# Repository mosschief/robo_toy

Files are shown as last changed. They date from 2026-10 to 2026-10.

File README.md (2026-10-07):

# Tank: a tough Arduino robot toy

A kid-proof robot on a printed tracked base. Its upper body turns at the waist,
the arms and waist click instead of breaking, and it has a 16 x 16 LED face,
a Wi-Fi camera and a distance sensor in the chest, and a phone control page. It reuses the electronics from
the Otto DIY "fat version" (Nano + shield, servos, LED matrix, buzzer).

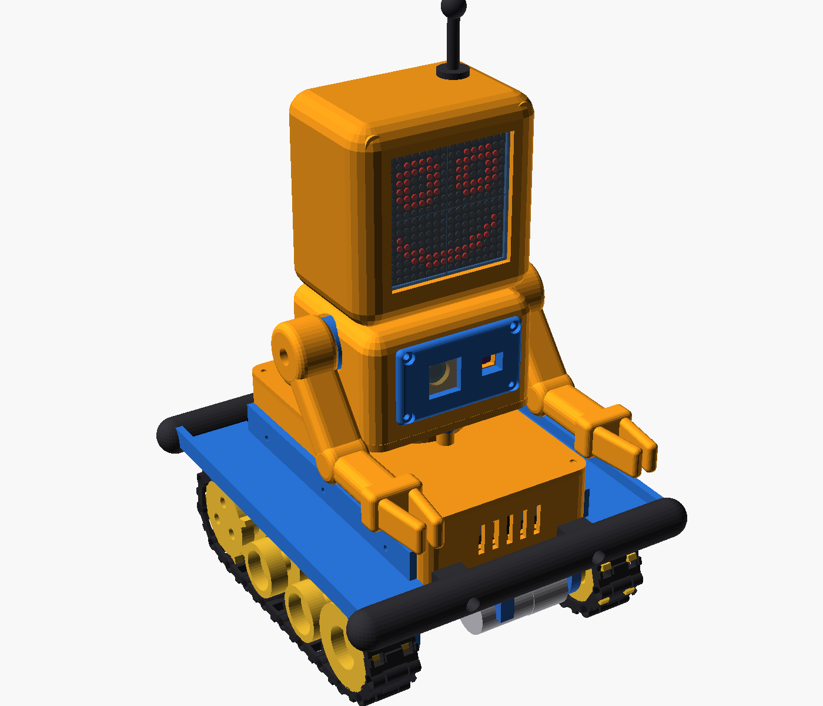
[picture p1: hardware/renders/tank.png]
Tank


| Folder | What's in it |
|---|---|
| [docs/BUILD.md](docs/BUILD.md) | parts list, printing, wiring, assembly, setup |
| [hardware/](hardware) | OpenSCAD source (`robot.scad`, `config.scad`), `stl/`, `renders/`, `export.sh` |
| [firmware/robot_body](firmware/robot_body) | Arduino Nano: face, arms, tracks, sensor, modes, `my_program.h` |
| [firmware/robot_cam](firmware/robot_cam) | ESP32-CAM: Wi-Fi, live video, phone control page |
| [tools/](tools) | `faces.txt` (draw faces) and `make_faces.py` |
| [concepts/](concepts) | the earlier concept rounds |

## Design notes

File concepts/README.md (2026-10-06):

# Robot toy concepts (round 1)

OpenSCAD concept models for a tough, kid-proof Arduino robot toy that reuses
Otto DIY Humanoid ("fat version") electronics.

- `concept_a_tank.scad`: tracks, two 2-joint arms, turning head
- `concept_b_brick.scad`: 4WD with bumper and fenders, two arms, carry handle (recommended)
- `concept_c_digger.scad`: two big wheels, turret with one 3-joint claw arm
- `tank_v2.scad`: chosen Tank, revision 2 (bought track chassis, ESP32-CAM)
- `tank_v4.scad`: current Tank (16x16 face from 4 MAX7219 modules)
- `tank_v3.scad`: Tank (camera and VL53L0X in the chest)
- `parts.scad`: shared placeholder parts (MAX7219 8x8, HC-SR04, SG90, wheels, tracks)
- `index.html` + `renders/`: concept sheet

Render a view:

```sh
xvfb-run -a openscad -o out.png --imgsize=1200,1000 \
  --camera=0,0,110,62,0,-32,820 --colorscheme=Tomorrow concepts/concept_b_brick.scad
```

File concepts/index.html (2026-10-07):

Arduino robot toy · full design

# Tank, ready to build

Everything needed to build Tank v4: 15 printable parts, a wiring plan, firmware for the Nano and the camera board, and a phone control page. All of it is in the repo on the claude/robot-toy-concepts-twiow6 branch, with step-by-step instructions in docs/BUILD.md.

## The robot

finalabout 216 × 222 × 300 mm15 printed parts

Final Tank assembly: printed orange body on a printed tracked base with link tracks, rubber bumpers, slim arms with claws, chest camera and distance sensor behind a blue guard, and a 16 by 16 LED fa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 Exploded view showing the lower body tub with battery and electronics tray, the lid, the bearing, waist plate and waist servo, the torso with its shoulder hubs, the one-piece arms and the head with 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 Printed tracked base on its own: blue deck and side frames, black printed link tracks, yellow sprockets, idlers and small road wheels, and a gear motor under the deck Rear view showing the power switch, charge port, PROG/RUN switch and Nano USB opening above the rear bumper

### How it is built

Base

Printed, a scaled-up SMARS-style design: one-piece deck and side frames, two JGA25-370 gear motors, sprockets and wheels on 608 bearings, and 21 printed links per track joined with M3 screws.

Lower body

Tub on the base deck holding the battery, Nano, motor driver, 5 V converter and charger. A lid on top carries the mode button and the waist bearing, and the waist servo stands below it.

Waist

The whole upper body turns 65° each way on a 6808 ball bearing in the lid. A clamp ring under the bearing means the robot can be picked up by its head.

Torso

Shoulder servos sit on internal bulkheads and the head bolts straight onto the top, so head, chest camera and arms turn together at the waist. The camera and distance sensor slide into rails behind the chest guard.

Head

Four 8×8 modules sit face-first in a carrier behind a 2 mm clear window. The back cap unscrews.

Arms

The slim v4 shape: one printed piece per arm with a fixed elbow bend and a two-finger claw. Only the shoulder moves.

Back panel

Power switch, USB-C charging, PROG/RUN switch and Nano USB, all above the bumper.

### Why it survives a kid

- Both shoulders and the waist have a spring clutch: a hard yank or twist makes the part click round instead of stripping the servo gears.
- Servos let go after 1.5 s of standing still, so pushing an arm by hand never fights the motor.
- PETG body with 4 walls, TPU bumpers and antenna, and the screens sit behind clear windows.
- Driving stops by itself 12 cm from a wall, and 0.4 s after the phone stops sending.
- It charges through USB-C, so the batteries never come out.

## Playing with it

Phone control page: camera view, distance and battery readout, a round orange joystick, Slow, Light and Bumper toggles, then buttons for faces, sounds, arm poses, modes and a Turn body slider

Join the Wi-Fi network Tank-XXXX (password tankrobot) and open 192.168.4.1. The page shows the camera with a joystick and buttons for faces, sounds, arm poses and modes, plus a slider that turns the body. It also shows the distance and battery readings.

Without a phone, the mode button on the lid switches modes, and the face shows the number:

Mode | What Tank does
1 Play | turns its body to look around, blinks, waves at a hand near its chest
2 Explore | drives on its own and turns away from obstacles
3 Dance | dances to a tune
4 My code | runs the program your kid writes in my_program.h
5 Face test | a wiring check for the face

Faces are drawn as text pictures in tools/faces.txt, so a kid can design new ones.

## What to buy

You already have the Otto Nano board, 3 servos, the buzzer and the LED modules (you need 4). An MG90S metal-gear servo for the waist is recommended.

Part | Qty | Approx. cost
JGA25-370 gear motors, 6 V, 130–200 rpm | 2 | $16–24
608 bearings, M8 x 45 bolts, M3 x 25 screws + nylocs for the tracks | 12 / 6 / 42 | $15
ESP32-CAM (AI-Thinker) + ESP32-CAM-MB USB adapter | 1 | $8–12
VL53L0X distance sensor (GY-VL53L0XV2) | 1 | $3
TB6612FNG motor driver | 1 | $3
6808-2RS ball bearing, 40 × 52 × 7 mm (waist) | 1 | $3–5
2 × 18650 cells, holder, 2S protection board | 1 | $12
USB-C 2S (8.4 V) charging module | 1 | $3
5 V 5 A buck converter (XL4015) | 1 | $4
Rocker switch, mini slide switch, 16 mm panel button | 1 each | $4
Compression springs ~8 mm OD × 12 mm | 3 | $3
M3 heat-set inserts, M3 and M2 screws, 5 M3 nuts | ~45 inserts | $8
2 mm clear PETG or polycarbonate sheet | small | $5
PETG and TPU filament | – | –

## Before you print

### Check the motors

JGA25-370 sellers differ in face screw spacing and shaft offset. Set MOT_* in hardware/config.scad and re-run export.sh. Print a few track links and one sprocket first and check they mesh. To use a bought TP101 chassis instead, set BASE = "bought".

### Check the LED modules

The face carrier fits the 32 × 32 mm modules (FC-16 style). If yours are the longer 50 × 32 mm boards, the carrier needs redrawing.

### Print a clutch first

Print one clutch_hub and one arm and test the click. If the click is too stiff or too loose, change the spring or CL_RH in config.scad.

### Not tested on hardware yet

Both firmwares compile, and the parts were fit-checked in the 3D model, but nothing has been printed or powered on. Expect a little tuning: servo trims, the face module order and track direction are all in config.h.

## Round 4: Tank v4

## Tank v4

chosenbought track chassisESP32-CAMVL53L0X2 arms × 2 joints

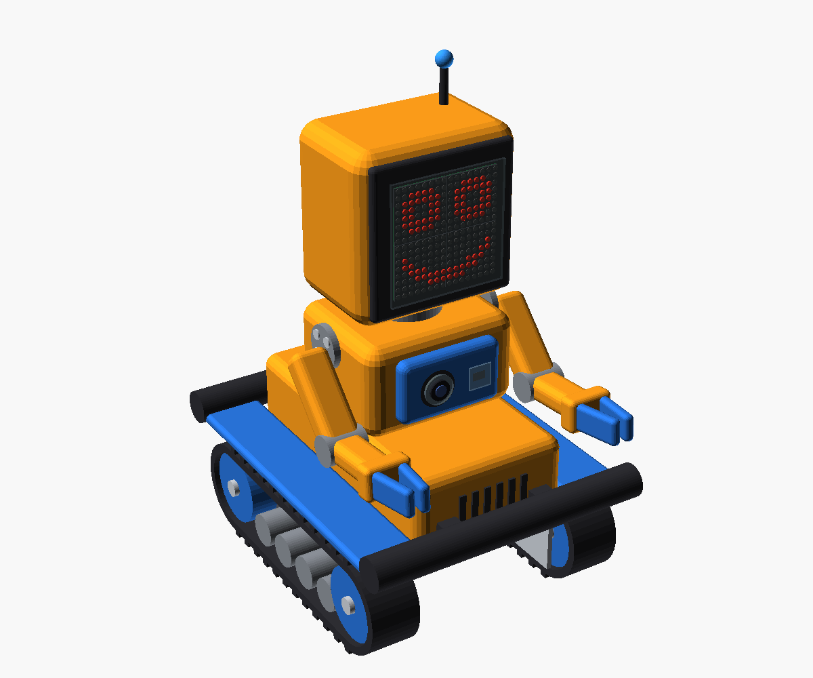
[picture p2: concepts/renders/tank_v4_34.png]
Tank v4: orange robot on a bought tank chassis with black tracks, rubber bumpers front and back, a head whose whole face is one square 16 by 16 LED display showing eyes and a smile, a camera and dis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
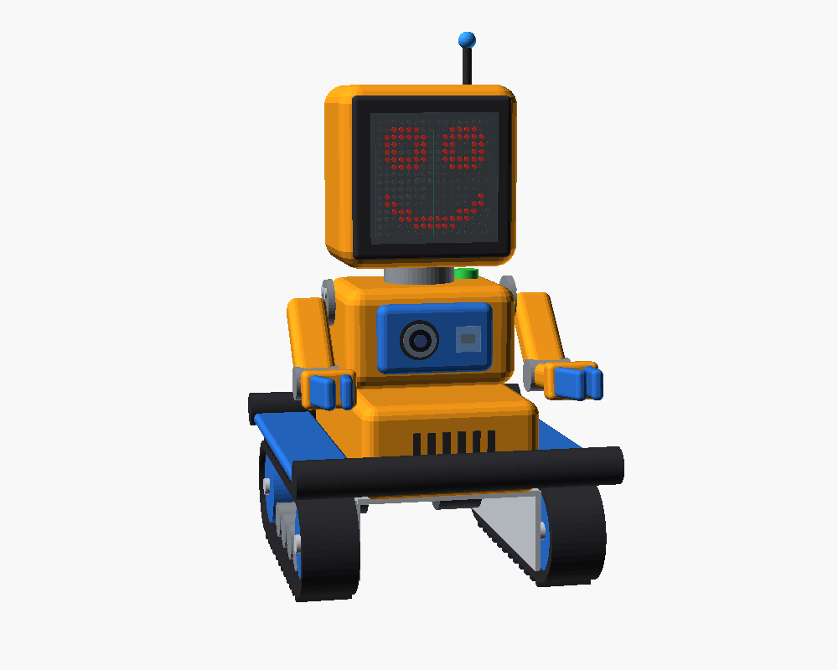
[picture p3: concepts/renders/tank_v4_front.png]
Tank v4 from the front, showing the square LED face and the camera and distance sensor in the chest
 

Size

about 172 × 222 × 270 mm tall (300 with antenna)

Drive

bought mini aluminium tank chassis, about 193 × 163 × 60 mm, metal-gear motors, plastic link tracks

Camera

ESP32-CAM (OV2640) in the chest behind a clear cover, looking where the robot drives

Distance

VL53L0X laser distance sensor beside the lens, up to about 1.2 m

Servos

5: shoulder + elbow per arm, head pan

Face

one 16×16 display (64 × 64 mm) made from four 8×8 MAX7219 modules in a square, on one chain; eyes and mouth are drawn on it, so they can move, blink, wink or turn into hearts

Chest

camera and distance sensor under a raised guard; buzzer grille on the lower body; power button on the shoulder

### What the camera adds

- Live video to a phone or tablet over Wi-Fi, with on-screen driving buttons, so your kid sees what the robot sees
- Simple vision tricks on the ESP32: follow a coloured ball, react when a face appears
- The distance sensor brings back "stop before the wall" and lets it measure how far away the ball is

### Trade-offs

- The camera no longer turns with the head, so to look around the robot turns its whole body
- The chest guard takes the hits the head used to avoid, so the lens sits behind a 2 mm clear cover recessed 3 mm

## How the electronics split

### ESP32-CAM: eyes and Wi-Fi

Runs the camera, the phone web page and any vision code. It sends short commands like "drive forward" or "happy face" to the Nano over a serial link (two wires, plus a two-resistor divider because the ESP32 is 3.3 V).

### Otto Nano: body

Keeps doing what it does in Otto: servos, the 16×16 face, the buzzer, and now the motor driver. It also reads the VL53L0X over I2C (pins A4 and A5), so it can stop by itself even with Wi-Fi off. Programmed in the Arduino IDE exactly as before, so it still works on its own without the camera.

### Bought chassis

The tracks, sprockets, road wheels and motors come as one tested unit. The printed body bolts to its aluminium deck with four M3 screws, and printed fenders cover the tracks so fingers stay out.

### Power

2 × 18650 cells (7.4 V) in the chassis feed the motors through the driver, and a 5 V 3 A buck converter feeds the Nano, servos, matrices and camera.

## Tank v4 parts list

Prices are typical Amazon/AliExpress prices in October 2026 and vary by seller.

Part | Qty | Source | Approx. cost
Otto Nano board + I/O shield | 1 | Have | –
Micro servos (MG90S metal gear recommended for the arms) | 5 | Have SG90s | $10 for 4 MG90S
MAX7219 8×8 matrix | 4 | Have (Otto + Amazon pack); buy one more if you only have 3 | –
Buzzer, Dupont cables | ✓ | Have | –
Mini aluminium tank chassis with motors ("mini TP101" style) | 1 | New | $35–65
ESP32-CAM (AI-Thinker, OV2640) + ESP32-CAM-MB USB adapter | 1 | New | $8–12
Motor driver (TB6612FNG or DRV8833) | 1 | New | $3
2 × 18650 holder with protection board + cells | 1 | New | $12
5 V 3 A buck converter + rocker switch | 1 | New | $4
VL53L0X distance sensor | 1 | New | $3
PETG + TPU filament | – | New | –

## Round 1 concepts

## A · Tank

tracks2 arms × 2 jointsturning head

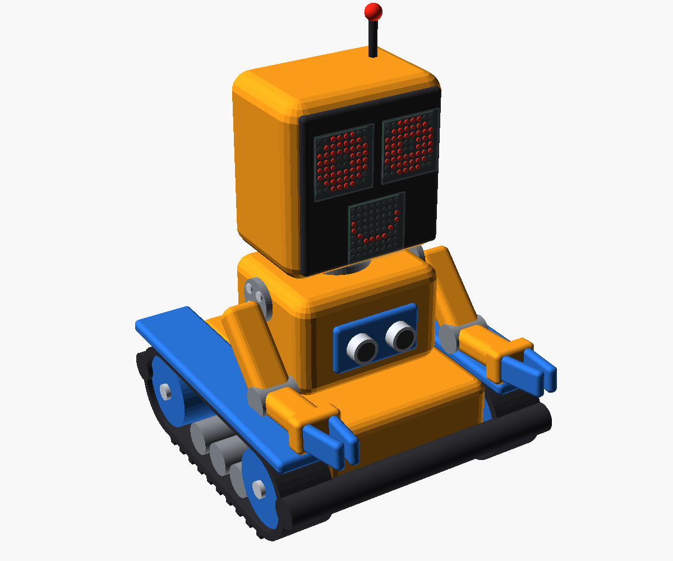
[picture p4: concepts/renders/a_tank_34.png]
Tank concept: orange robot on blue and black tracks with a square head showing two LED-matrix eyes and a smiling matrix mouth, ultrasonic sensor in the chest, two arms with claws
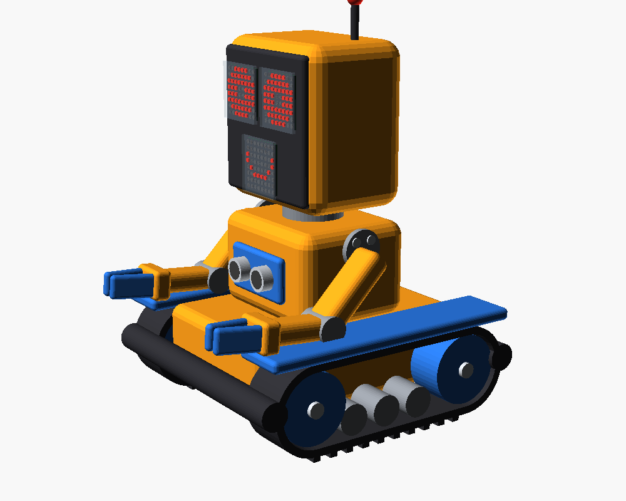
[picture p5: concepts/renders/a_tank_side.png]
Tank concept from the right side
 

A classic tracked robot with a square head that turns left and right. Both arms have a shoulder and an elbow and end in fixed claws, so it can push, scoop and wave.

Size

about 180 × 185 × 265 mm tall (with antenna)

Drive

2 gear motors, TPU tracks with grousers

Servos

5: shoulder + elbow per arm, head pan

Eyes

two more 8×8 matrices chained to the mouth

Sensor

HC-SR04 in the chest behind a guard

- Climbs over toys and rugs
- Most "robot" looking, the head turn is very expressive
- Printed tracks are the most failure-prone part of all three designs
- Tall, so it is the one most likely to tip on a hard turn
- Longest print and assembly

## B · Brick

recommended4WD2 arms with gripperscarry handle

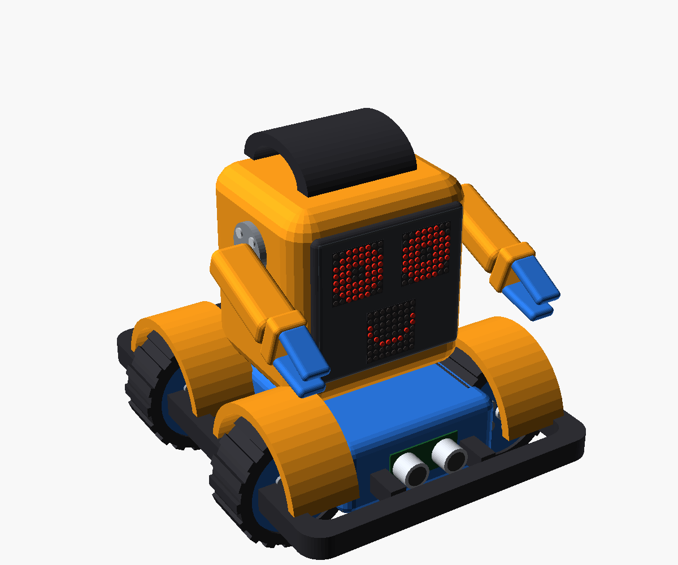
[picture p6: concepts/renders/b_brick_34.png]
Brick concept: rounded orange block body on a blue chassis with four chunky black tyres under orange fenders, a black rubber bumper all around, LED-matrix face behind a window, two arms with blue gr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
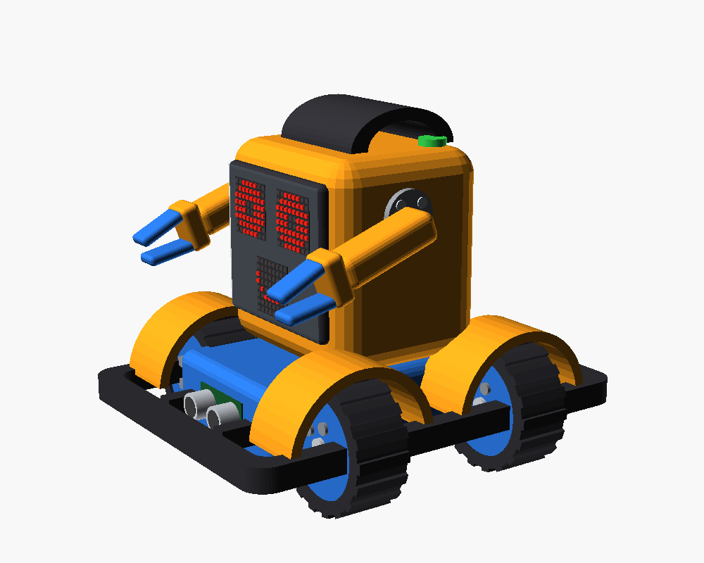
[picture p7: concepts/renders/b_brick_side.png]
Brick concept from the right side
 

One big rounded block for head and body, low and wide on four skid-steer wheels. The whole face (two eye matrices and the mouth) sits behind one clear window, and the handle on top lets your kid carry it around.

Size

about 190 × 250 × 205 mm tall

Drive

4 gear motors (or 2 driven + 2 idlers), TPU tyres

Servos

2 to 4: shoulder per arm, optional gripper per arm

Eyes

two more 8×8 matrices chained to the mouth

Sensor

HC-SR04 in the front grille, behind the bumper

- Toughest: bumper and fenders take every hit before the body does
- Low centre of gravity, very hard to flip
- Simplest to print and to repair
- No head turn (could add one later as a neck servo)
- Arms are simpler than the Tank's

## C · Digger

2 big wheels1 claw arm × 3 jointsrotating turret

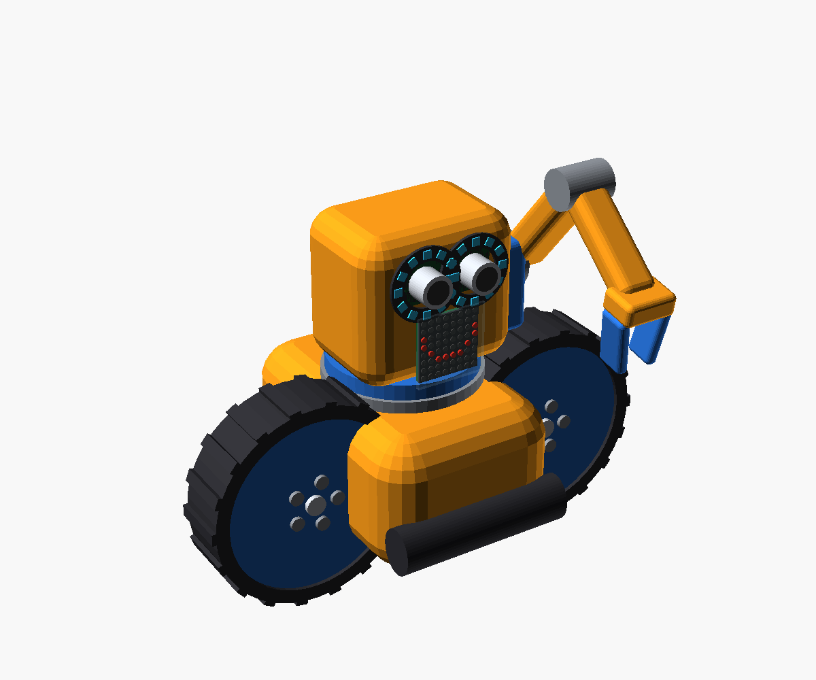
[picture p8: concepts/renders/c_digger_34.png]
Digger concept: two large black wheels on a rounded orange pod, a rotating turret head with ultrasonic sensor eyes ringed by blue LED rings, an LED-matrix mouth, and one long jointed arm with a claw
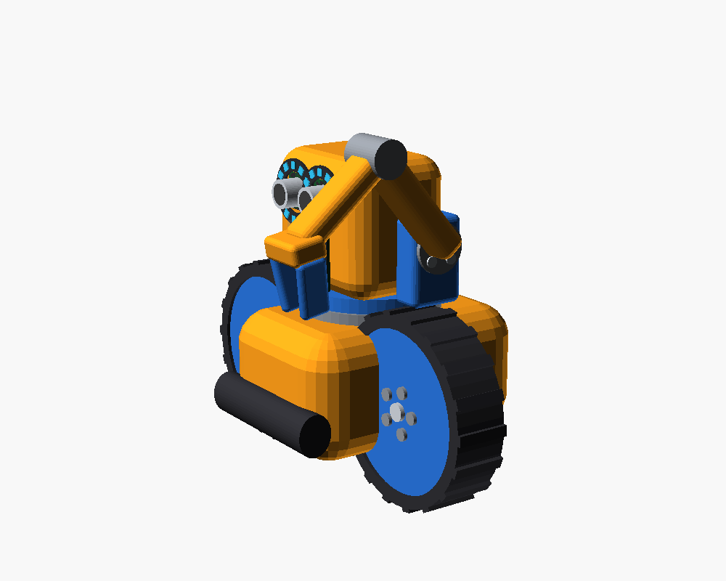
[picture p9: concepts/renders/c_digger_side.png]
Digger concept from the right side
 

Two big wheels taller than the body plus a rear skid, with a turret on top carrying one long excavator-style arm. The ultrasonic sensor becomes the eyes, like Otto, ringed with colour LED rings.

Size

about 165 × 160 × 230 mm tall (arm raised)

Drive

2 gear motors, 104 mm TPU tyres, rear skid

Servos

4: turret, shoulder, elbow, claw

Eyes

2 × WS2812 12-LED rings around the HC-SR04

Sensor

HC-SR04 as the eyes

- The arm can actually pick things up
- Big wheels roll over obstacles and protect the body
- Familiar Otto face
- One long arm is a lever: it is the part most likely to get yanked
- Needs new LED rings for the eyes
- Turns in place but the skid drags on carpet

## Parts: what you have vs. what's new

Otto "fat version" kit parts are from its Printables bill of materials. I couldn't open the Amazon listing, so I've assumed it is the common MAX7219 8×8 module (32 × 32 mm, 5-pin); tell me if it's different.

Part | A · Tank | B · Brick | C · Digger | Source
Otto Nano board + I/O shield | 1 | 1 | 1 | Otto kit
Micro servos (SG90 or MG90S) | 5 | 2–4 | 4 | Otto kit (has 6)
HC-SR04 ultrasonic | 1 | 1 | 1 | Otto kit
MAX7219 8×8 matrix (mouth) | 1 | 1 | 1 | Otto kit / your Amazon pack
MAX7219 8×8 matrix (eyes) | 2 | 2 | – | Your Amazon pack, if it's a multi-pack
Buzzer, Dupont cables | ✓ | ✓ | ✓ | Otto kit
Gear motors (metal-gear N20 or TT) | 2 | 2–4 | 2 | New
Motor driver (DRV8833 or TB6612) | 1 | 1–2 | 1 | New
WS2812 12-LED rings | – | – | 2 | New
2 × 18650 holder + 5 V 3 A buck + switch | 1 | 1 | 1 | New (the Otto battery can't run drive motors and servos together)
TPU filament (tyres, tracks, bumpers) | most | some | some | New

Pin budget fits the Nano in every concept: all three matrices share one 3-wire chain, the motor driver takes 4 PWM pins (3, 5, 6, 11), the HC-SR04 2 pins, the buzzer 1, and servos go on the remaining pins. Otto's Bluetooth module would still fit for phone control.

## How it stays in one piece

### Arms that give way

Each arm attaches to its servo through a magnetic or spring-detent coupler, so a yank pops the arm off instead of stripping the servo gears. Arms get metal-gear MG90S servos, which are drop-in replacements for the SG90.

### Soft outside, hard inside

Tyres, tracks, bumpers and the handle are TPU. The shell is PETG with 4 walls and 30% gyroid infill, not PLA, which goes brittle and cracks on drops.

### Protected screens

The matrices sit recessed behind a 2 mm polycarbonate or PETG window, so little fingers and crashes never touch the LEDs.

### Floating electronics

The Nano, driver and buck converter sit on one tray on foam pads, with heat-set brass inserts instead of screws threaded into plastic, so it can be opened and fixed many times.

### Kid-safe power

Lithium cells live behind a screwed battery door with a protected charger. Any magnets are fully enclosed inside printed parts; for a child under about 6 I'd use the spring detent instead of magnets.

### Programmable

Standard Arduino IDE (and Otto Blockly-style blocks later), with a small library of moves, faces and sounds so new tricks are a few lines of code.

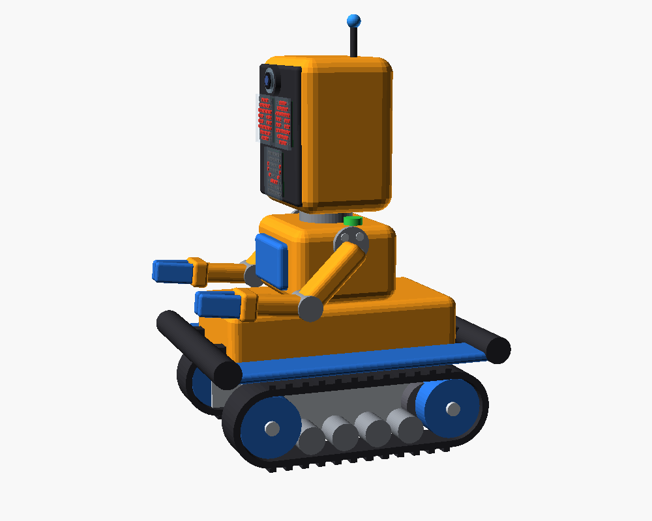
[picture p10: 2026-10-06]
concepts/renders/tank_v2_side.png

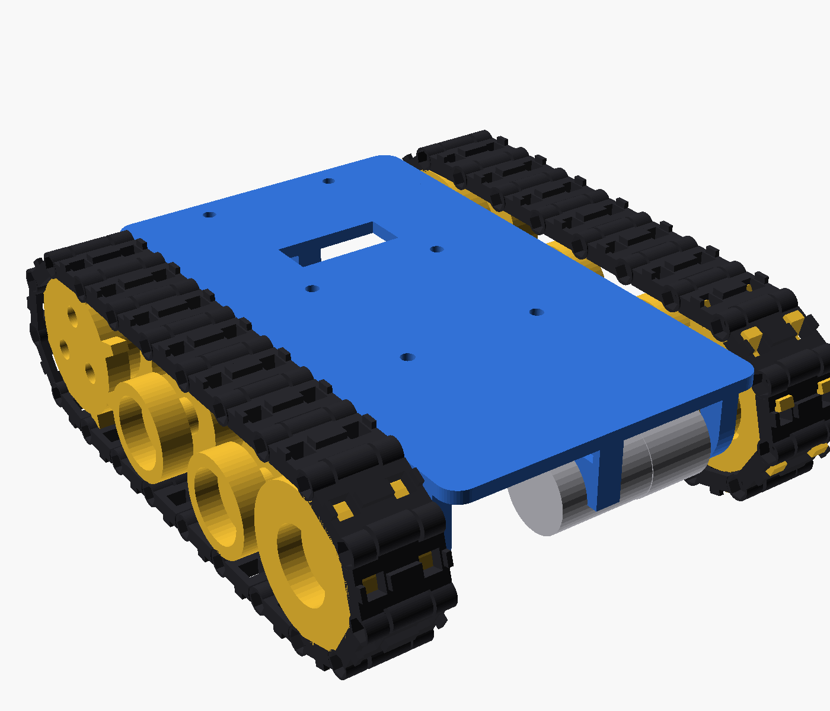
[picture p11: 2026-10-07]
hardware/renders/base.png

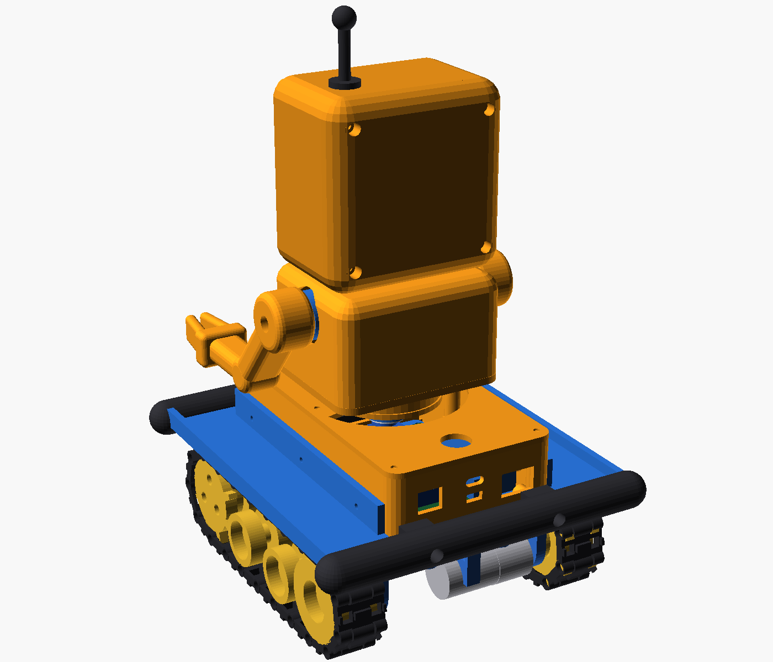
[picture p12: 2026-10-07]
hardware/renders/tank_back.png

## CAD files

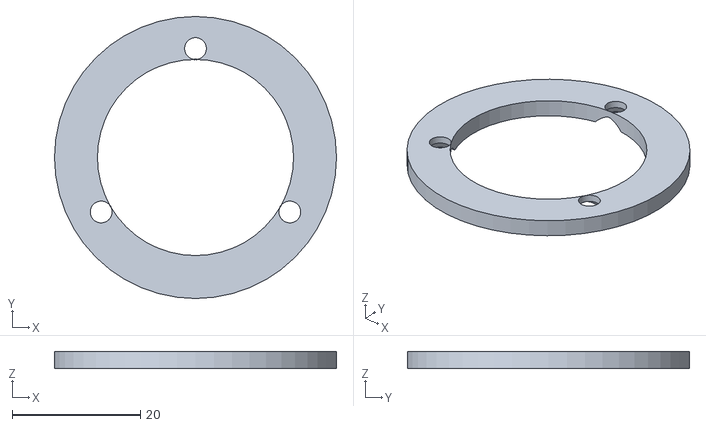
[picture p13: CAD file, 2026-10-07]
hardware/stl/clamp_ring.stl
44.0 x 44.0 x 2.70

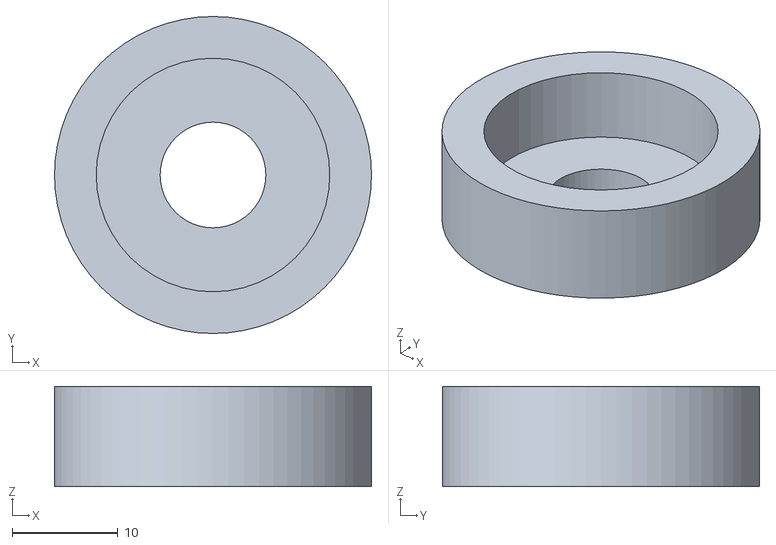
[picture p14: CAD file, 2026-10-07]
hardware/stl/road_wheel_half.stl
30.0 x 30.0 x 9.50

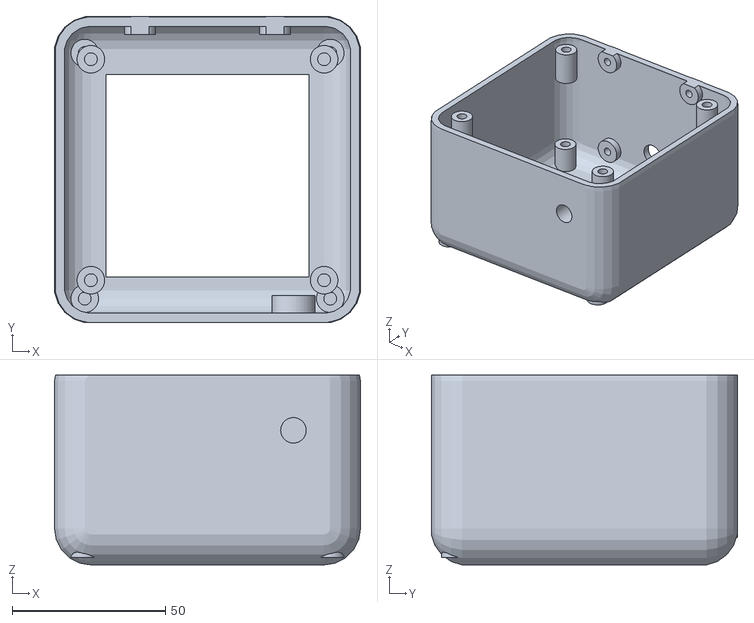
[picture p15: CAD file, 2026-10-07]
hardware/stl/head_front.stl
99.7 x 99.9 x 61.9

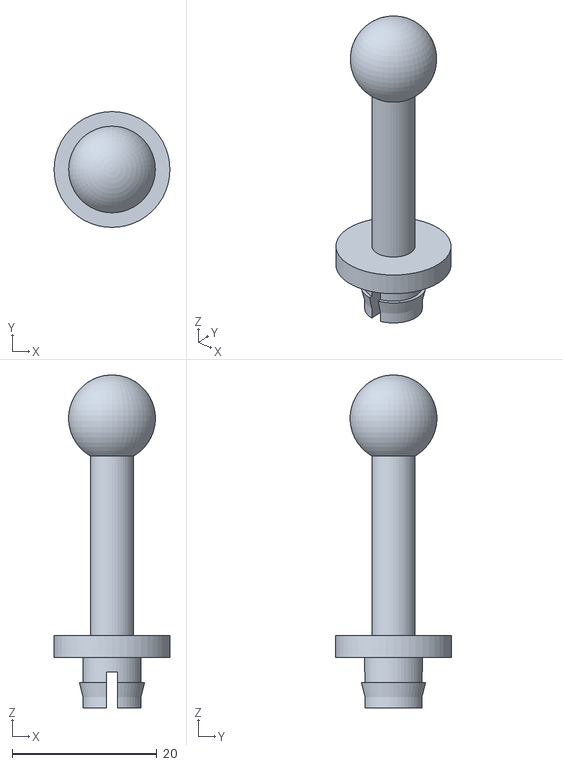
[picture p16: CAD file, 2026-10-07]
hardware/stl/antenna.stl
16.0 x 16.0 x 46.0

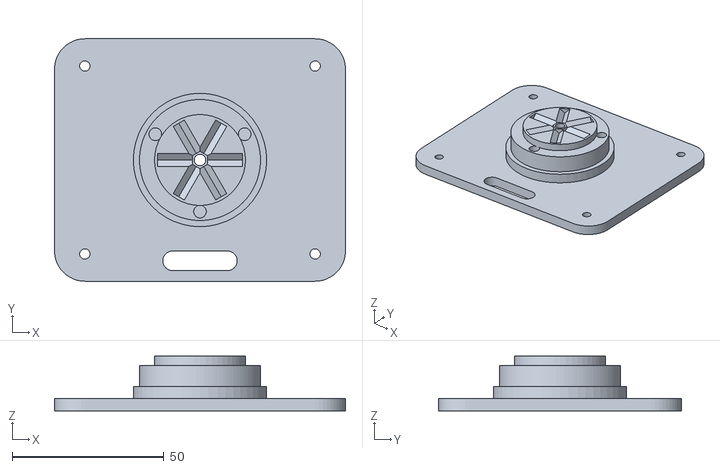
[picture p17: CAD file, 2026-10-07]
hardware/stl/waist.stl
96.0 x 80.0 x 18.0

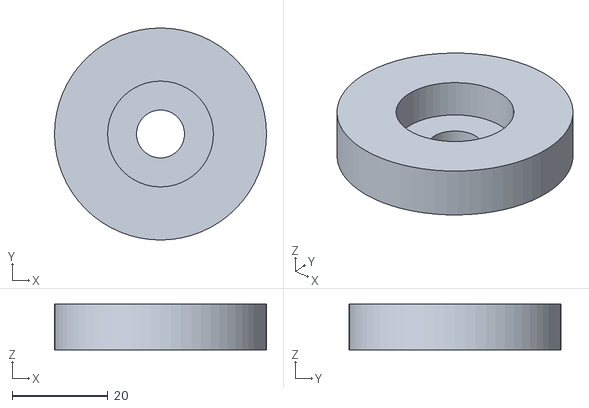
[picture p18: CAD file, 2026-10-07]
hardware/stl/wheel_half.stl
44.3 x 44.3 x 9.50

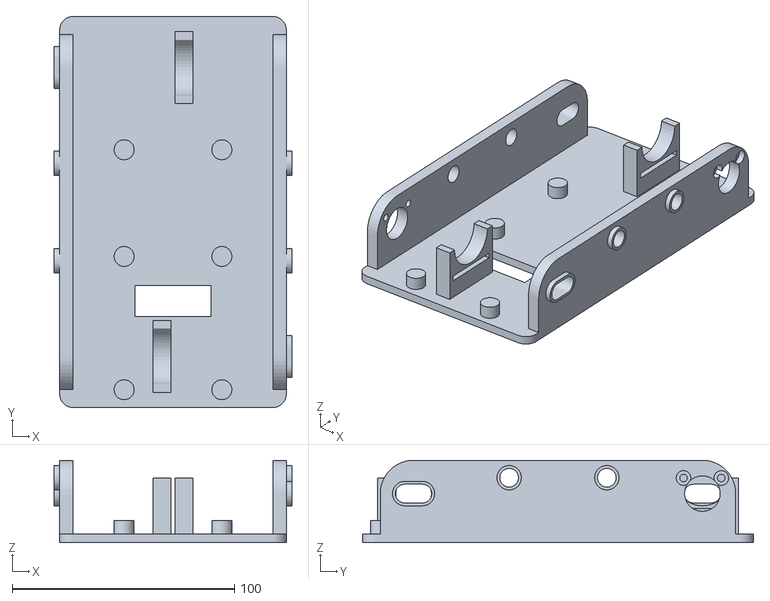
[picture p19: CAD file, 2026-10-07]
hardware/stl/base_frame.stl
107.0 x 176.0 x 37.1

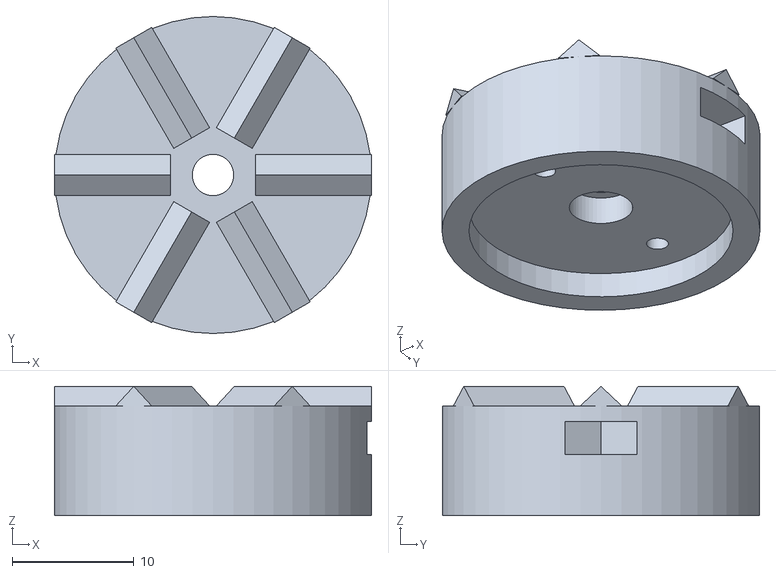
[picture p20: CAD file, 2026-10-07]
hardware/stl/clutch_hub.stl
26.0 x 26.0 x 10.6

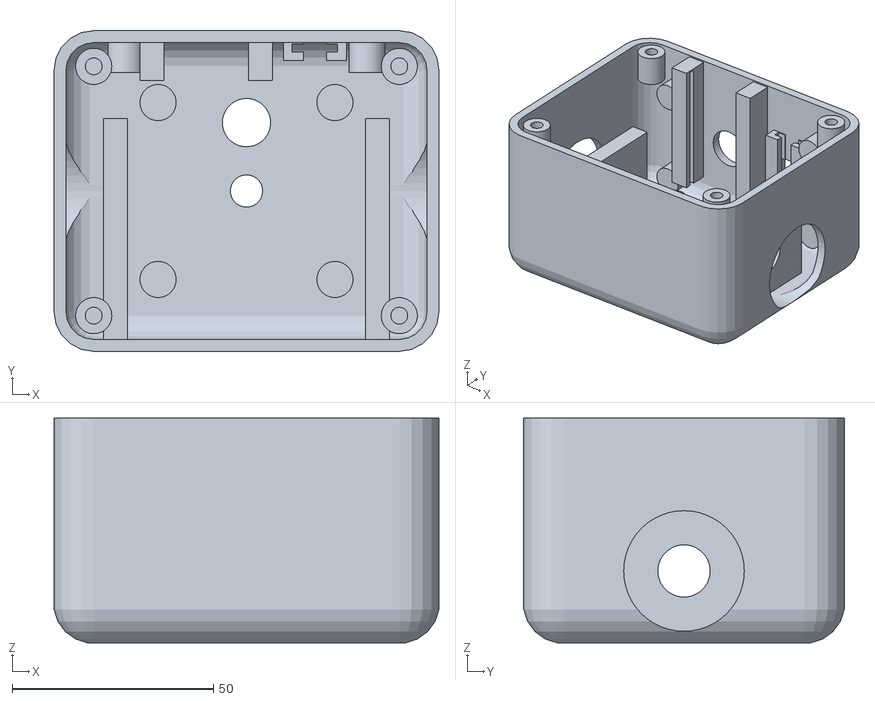
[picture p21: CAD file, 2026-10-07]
hardware/stl/torso.stl
95.8 x 79.8 x 55.9

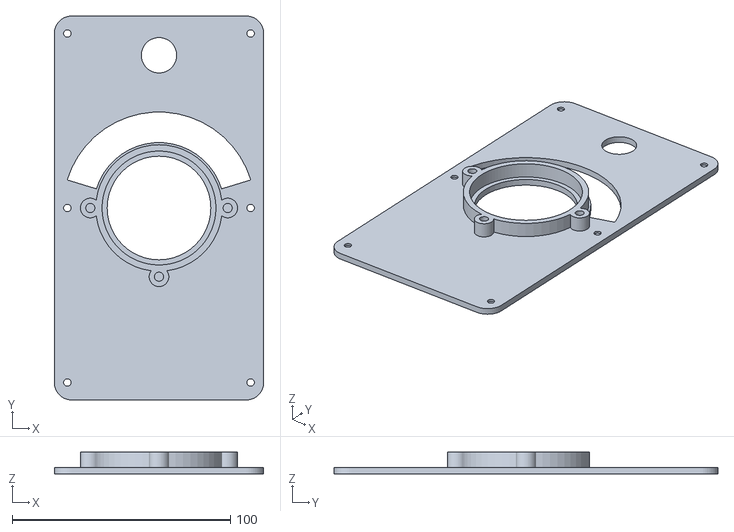
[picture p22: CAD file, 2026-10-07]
hardware/stl/lid.stl
96.0 x 176.0 x 10.0

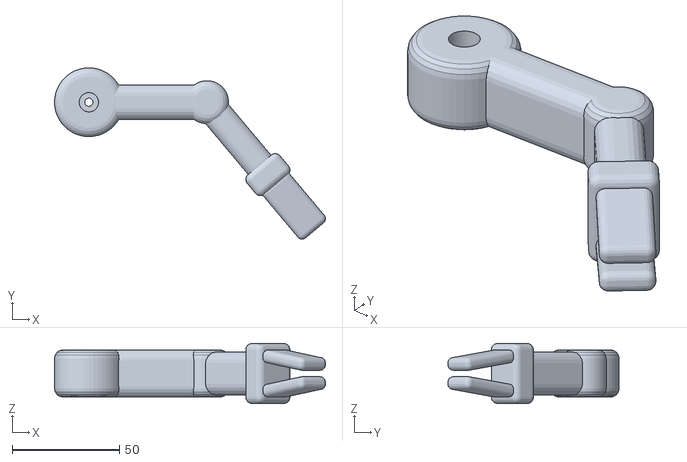
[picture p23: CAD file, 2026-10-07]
hardware/stl/arm.stl
126.1 x 79.7 x 27.9

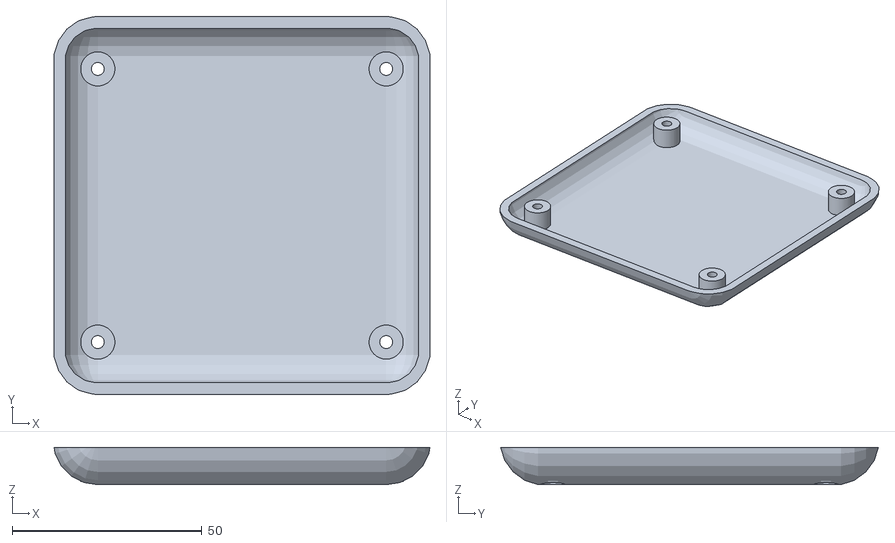
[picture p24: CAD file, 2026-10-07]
hardware/stl/head_back.stl
99.1 x 99.6 x 9.85

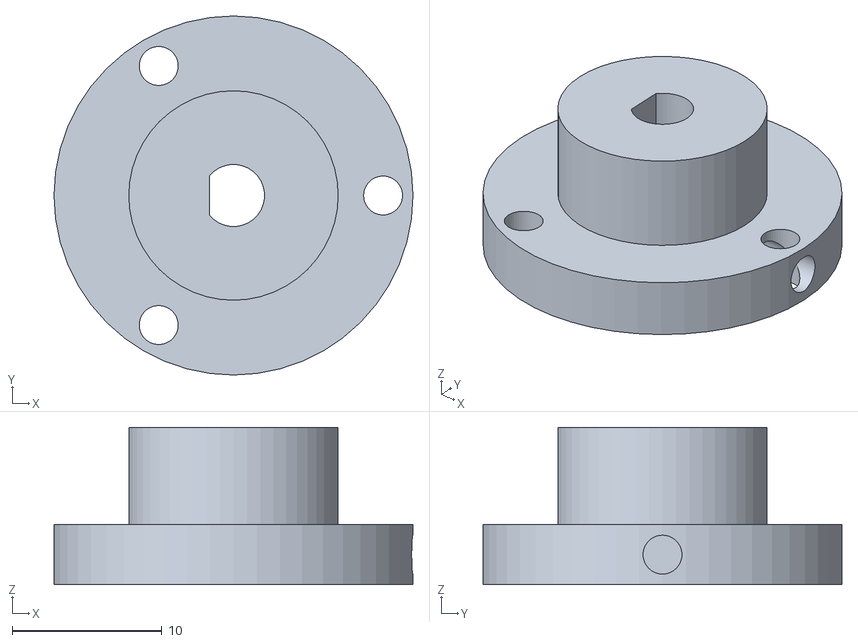
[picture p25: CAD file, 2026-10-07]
hardware/stl/sprocket_hub.stl
24.0 x 24.0 x 10.5

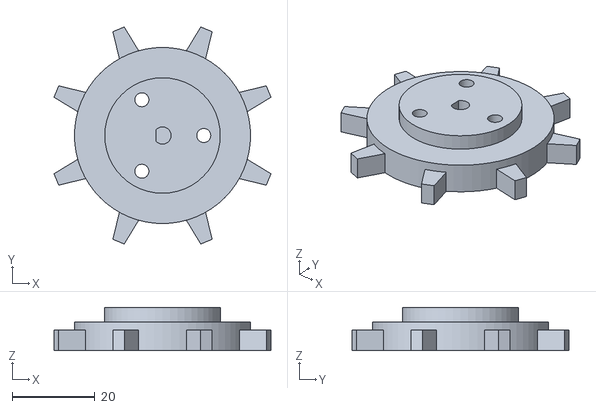
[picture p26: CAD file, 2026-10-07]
hardware/stl/sprocket_half.stl
52.6 x 52.6 x 10.5

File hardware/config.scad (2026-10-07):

// Tank robot: every dimension in one place (mm).
// Change these to match the parts you actually bought, then re-export.

$fn = 48;

// ---------- print / fasteners ----------
WALL      = 3;      // shell wall. Print PETG, 4 perimeters, 30% gyroid.
INS_D     = 4.2;    // hole for an M3 x 5.7 brass heat-set insert
INS_L     = 6;
BOSS_D    = 9;
M3        = 3.4;    // M3 clearance
M3_HEAD   = 6.6;    // M3 socket head counterbore
M2_PILOT  = 1.8;    // servo tab screws (self-tapping M2)
NUT_AF    = 5.9;    // M3 nut across flats (+clearance)
NUT_T     = 2.7;
CLR       = 0.3;    // general fit clearance

// ---------- MG90S / SG90 micro servo ----------
SV_L      = 22.8;   // body length (long axis)
SV_W      = 12.2;   // body width
SV_TAB_L  = 32.2;   // length across mounting tabs
SV_TAB_T  = 2.5;    // tab thickness
SV_BELOW  = 15.9;   // body bottom to underside of tabs
SV_ABOVE  = 4.3;    // top of tabs to top of body
SV_SPLINE = 12.6;   // top of tabs to tip of output spline
SV_SCREW  = 27.8;   // tab screw hole spacing
SV_SHAFT  = 5.6;    // output shaft offset from body centre along long axis
SV_DOME_D = 12.0;   // gear dome around the spline

// Round "disk" servo horn that comes with the servo
HORN_D    = 21.0;
HORN_T    = 2.0;
HORN_HOLE_R = 7.5;  // radius of the screw holes used to fix horn to the clutch hub

// ---------- breakaway clutch (one design, used at the shoulders and the waist) ----------
// Horn hub (on the servo) has radial V ridges; the limb has matching grooves.
// An M3 screw + compression spring (8 mm OD, ~12 mm long) presses them together.
// A hard yank makes the limb click round instead of stripping servo gears.
CL_D      = 26;
CL_T      = 9;      // hub body thickness
CL_RIDGES = 6;
CL_RH     = 1.6;    // ridge height
CL_RW     = 3.4;    // ridge base width
HUB_FACE  = 10.1;   // tab top -> hub servo-side face (horn sits on the spline)
LIMB_GAP  = 0.3;
LIMB_FACE = HUB_FACE + CL_T + LIMB_GAP;   // tab top -> limb contact face (19.4)
WELL_D    = 30;     // recess the hub sits in, so limbs stay close to the body
SPRING_D  = 9;      // counterbore for spring + washer

// ---------- bought chassis ----------
// "mini TP101" style aluminium tank chassis. Measure yours and edit.
CH_L = 193; CH_W = 163; CH_H = 60; TR_W = 30;
DECK_GAP = (CH_W - 2 * TR_W);             // free width between the tracks

// ---------- printed tracked base (BASE = "printed") or a bought TP101 ("bought") ----------
BASE = "printed";
TK_P   = 20;            // track link pitch
TK_W   = 26;            // track link width
TK_N   = 21;            // links per track
SPR_T  = 8;             // sprocket teeth
TK_R   = TK_P / (2 * sin(180 / SPR_T));     // sprocket pitch radius (26.1)
TK_S   = (TK_P * TK_N - SPR_T * TK_P) / 2;  // sprocket-to-idler axle spacing (130)
KN_D   = 8;             // link hinge knuckle diameter (M3 screw pin inside)
LINK_T = 5;             // link plate thickness
GROUSER = 2;            // grip rib on the outside of each link
HORN_H = 6;             // guide horn on the inside of each link
TK_X   = CH_W / 2 - TR_W / 2;               // track centre line (x)
FR_X   = 51;            // outer face of the side frames
FR_T   = 6;             // side frame thickness
DECK_T = 4;
Z_AXLE = 8 - TK_R - KN_D / 2;               // wheel axles; track top ends up ~8 above the deck
WHEEL_R = TK_R - KN_D / 2;                  // idler radius (rolls on the knuckles)
RW_R   = 15;            // road wheels, under the bottom run
Z_RW   = Z_AXLE - TK_R + KN_D / 2 + RW_R;   // road wheel axles
BRG608 = [8, 22, 7];    // skateboard bearing: bore, OD, width
// JGA25-370 gear motor (check yours): gearbox, can, D shaft offset from the can centre
MOT_GB_D = 25;  MOT_CAN_D = 24.4;  MOT_LEN = 52;
MOT_SHAFT_D = 4;  MOT_SHAFT_FLAT = 3.5;  MOT_OFF = 7;  MOT_HOLE_SP = 17;

// ---------- lower body (sits on the chassis deck) ----------
LB = [96, 176, 47];     // X width, Y length, Z height of the tub
LB_R = 8;
LID_T = 3;

// ---------- torso ----------
TO = [96, 80, 56];
TO_R = 10;
SHOULDER_Z = 38;        // shoulder axis height above torso bottom
SHOULDER_Y = 0;

// ---------- head ----------
HD = [100, 72, 100];
HD_R = 12;
FACE_Z = 52;            // centre of the 16x16 display above head bottom
NECK_GAP = 1;           // head bottom to torso top

// ---------- arms ----------
ARM_T = 22;             // arm thickness along the shoulder axis (X)
ARM_W = 16;             // upper arm width (Y)
ARM_UP = 55;            // shoulder axis to elbow
ARM_FORE = 42;          // elbow to claw
ARM_BEND = 50;          // fixed elbow bend, degrees forward

// ---------- face: 4 x MAX7219 8x8 modules in a 2x2 square ----------
MX = 32.2;              // module outline (FC-16 style, 32 x 32 PCB)
MX_DEPTH = 9;           // matrix block + PCB, without the header pins
MX_GAP = 0.8;           // printed divider between modules
FACE_WIN = 66;          // visible opening in the head
WIN_SHEET = [72, 72, 2];// clear PETG / polycarbonate sheet

// ---------- chest: ESP32-CAM + VL53L0X ----------
CAM_X = -10;  CAM_Z = 30;      // lens centre on the torso front
TOF_X = 17;   TOF_Z = 30;
CAM_PCB = [27, 40.5, 1.6];
TOF_PCB = [10.7, 25, 1.6];      // GY-VL53L0XV2 breakout, mounted upright
CHEST_WIN = [52, 26, 2];        // clear window sheet over lens + sensor

// ---------- waist: the upper body turns on a 6808 bearing in the lid ----------
BR = [40, 52, 7];       // 6808-2RS bearing: bore, outside diameter, width
BR_IN_OD  = 44.5;       // inner race outside diameter (clamp/collar stay inside this)
BR_OUT_ID = 47.5;       // outer race inside diameter (shoulders stay outside this)
BR_HOUSE_OD = 58;       // printed housing on the lid
CAP_T = 3;              // bearing cap on top of the housing
WAIST_GAP = 1;          // cap top to waist plate
WP = [96, 80, 4];       // waist plate (torso footprint)
WAIST_RANGE = 65;       // degrees each way from straight ahead

// ---------- world placement (z = 0 is the chassis deck top) ----------
Z_LB    = 0;
Z_WAIST = LB[2] + LID_T + BR[2] + CAP_T + WAIST_GAP;   // waist plate bottom
Z_TORSO = Z_WAIST + WP[2];
Z_HEAD  = Z_TORSO + TO[2] + NECK_GAP;

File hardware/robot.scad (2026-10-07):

// Tank robot: printable parts.
// Render one part:  openscad -D 'part="torso"' -o torso.stl robot.scad
// Parts list: see PARTS below or hardware/export.sh.
include <base.scad>

part = "none";

// ======================================================================
// LOWER BODY: tub that bolts to the chassis deck. Holds battery,
// Nano + shield, motor driver, buck converter, charger, buzzer, switches.
// Local frame: centred in X/Y, bottom at z = 0, front faces -Y.
// ======================================================================
LB_BOSS = [for (x = [-1, 1], y = [-80, 0, 80]) [x * (LB[0] / 2 - 6), y]];
TORSO_BOSS = [for (x = [-1, 1], y = [-1, 1]) [x * 38, y * 31]];
BUMPER_X = 36; BUMPER_Z = 14;
FENDER_Y = [-60, 0, 60]; FENDER_Z = 22;
TRAY_BOSS = [for (x = [-1, 1], y = [-22, 68]) [x * 33, y]];   // clear of the lid columns and rear bumper bosses

module tub(size, r, wall) {
    intersection() {
        difference() {
            translate([-size[0] / 2, -size[1] / 2, 0]) rbox([size[0], size[1], size[2] + r], r);
            translate([-size[0] / 2 + wall, -size[1] / 2 + wall, wall])
                rbox([size[0] - 2 * wall, size[1] - 2 * wall, size[2] + r], max(r - wall, 1));
        }
        translate([-size[0], -size[1], 0]) cube([2 * size[0], 2 * size[1], size[2]]);
    }
}

module slot(len, w, h) { hull() for (x = [-len / 2, len / 2]) translate([x, 0, 0]) cylinder(d = w, h = h); }

module lower_body() {
    L = LB[1]; W = LB[0]; H = LB[2];
    difference() {
        union() {
            tub(LB, LB_R, WALL);
            intersection() {
            translate([-W / 2, -L / 2, 0]) rbox([W, L, H + LB_R], LB_R);
            union() {
            // lid screw columns
            for (p = LB_BOSS) translate([p[0], p[1], 0]) insert_boss(H);
            // bumper bosses, front and back
            for (y = [-1, 1], x = [-1, 1]) translate([x * BUMPER_X, y * (L / 2 - WALL), BUMPER_Z])
                rotate([y * 90, 0, 0]) insert_boss(10);
            // fender bosses on both sides
            for (s = [-1, 1], y = FENDER_Y) translate([s * (W / 2 - WALL), y, FENDER_Z])
                rotate([0, s * -90, 0]) insert_boss(9);
            // electronics tray standoffs
            for (p = TRAY_BOSS) translate([p[0], p[1], 0]) insert_boss(11, 8);
            // battery cradle (2 x 18650 holder, ~77 x 41 mm) with strap slots
            for (y = [-77.5, -33.5]) translate([-40, y - 1.5, 0]) cube([80, 3, 18]);
            for (x = [-1, 1]) translate([x * 41.5 - 1.5, -77.5, 0]) cube([3, 44, 10]);
            // buzzer holder behind the grille (12 mm passive buzzer)
            translate([0, -L / 2 + WALL, 30]) rotate([-90, 0, 0]) cylinder(d = 16, h = 9);
            // waist servo tower: the servo drops in from the top, tabs rest on the rim
            waist_frame() translate([-11.5, -8.9, -(WS_TAB_Z - WALL)]) cube([34.2, 17.8, WS_TAB_Z - WALL - SV_TAB_T]);
            }}
        }
        // chassis mounting slots + motor wire hole in the floor
        for (p = LB_FLOOR_SCREWS) translate([p[0], p[1], -1]) slot(10, M3, WALL + 2);
        translate([-17, 33, -1]) cube([34, 14, WALL + 2]);
        // waist servo pocket, tab screw pilots, cable slot
        waist_frame() {
            translate([SV_SHAFT - SV_L / 2 - 0.4, -SV_W / 2 - 0.4, -SV_TAB_T - SV_BELOW - 0.5]) cube([SV_L + 0.8, SV_W + 0.8, 40]);
            for (s = [-1, 1]) translate([SV_SHAFT + s * SV_SCREW / 2, 0, -SV_TAB_T - 8]) cylinder(d = M2_PILOT, h = 9);
            translate([SV_SHAFT + SV_L / 2 - 1, -3, -SV_TAB_T - 14]) cube([8, 6, 15]);
        }
        // insert holes: lid columns (from the top), bumpers, fenders, tray
        for (p = LB_BOSS) translate([p[0], p[1], H]) mirror([0, 0, 1]) insert_hole();
        for (y = [-1, 1], x = [-1, 1]) translate([x * BUMPER_X, y * (L / 2 + 1), BUMPER_Z])
            rotate([y * 90, 0, 0]) insert_hole(INS_L + 1);
        for (s = [-1, 1], y = FENDER_Y) translate([s * (W / 2 + 1), y, FENDER_Z])
            rotate([0, s * 90, 0]) mirror([0, 0, 1]) insert_hole(INS_L + 1);
        for (p = TRAY_BOSS) translate([p[0], p[1], 11]) mirror([0, 0, 1]) insert_hole();
        // battery strap slots
        for (y = [-77.5, -33.5]) translate([-11, y - 3, 12]) cube([22, 6, 3.5]);
        // front: speaker grille + buzzer bore
        for (x = [-16 : 8 : 16]) translate([x - 1.7, -L / 2 - 1, 22]) cube([3.4, WALL + 2, 16]);
        translate([0, -L / 2 + WALL - 0.1, 30]) rotate([-90, 0, 0]) cylinder(d = 12.6, h = 10);
        // back, all above the bumper: power rocker (KCD1, 19 x 13), USB-C charge port,
        // PROG/RUN slide switch, Nano USB
        translate([-26 - 9.7, L / 2 - WALL - 1, 28 - 6.6]) cube([19.4, WALL + 2, 13.2]);
        translate([0, L / 2 + 1, 35]) rotate([90, 0, 0]) hull() for (x = [-3, 3]) translate([x, 0, 0]) cylinder(d = 4.6, h = WALL + 2);
        translate([26 - 7, L / 2 - WALL - 1, 25]) cube([14, WALL + 2, 12]);
        translate([-4.6, L / 2 - WALL - 1, 24]) cube([9.2, WALL + 2, 4.6]);
    }
}

// Lid with the waist bearing housing on top. The 6808 bearing presses into the
// housing from above and is held by the bearing cap.
CAP_LOBE_A = [0, 180, 270];
CAP_LOBE_R = BR_HOUSE_OD / 2 + 2.5;
CABLE_R = [BR_HOUSE_OD / 2 + 1, BR_HOUSE_OD / 2 + 15];   // cable arc: inner, outer radius

module lid() {
    W = LB[0]; L = LB[1];
    HH = LID_T + BR[2];
    difference() {
        union() {
            translate([-W / 2, -L / 2, 0]) rslab([W, L, LID_T], LB_R);
            cylinder(d = BR_HOUSE_OD, h = HH);
            for (a = CAP_LOBE_A) rotate(a) translate([CAP_LOBE_R, 0, 0]) cylinder(d = 9, h = HH);
        }
        for (p = LB_BOSS) translate([p[0], p[1], -1]) {
            cylinder(d = M3, h = LID_T + 2);
            translate([0, 0, LID_T - 1.6]) cylinder(d1 = M3, d2 = 6.4, h = 1.61);   // countersink
        }
        // bearing seat (outer race sits on the lid) and the opening under it
        translate([0, 0, LID_T]) cylinder(d = BR[1] + 0.15, h = BR[2] + 1, $fn = 96);
        translate([0, 0, -1]) cylinder(d = BR_OUT_ID, h = HH + 2);
        for (a = CAP_LOBE_A) rotate(a) translate([CAP_LOBE_R, 0, HH + 0.01]) mirror([0, 0, 1]) insert_hole();
        // the torso cables swing through this arc as the waist turns
        rotate(90 - WAIST_RANGE - 8) rotate_extrude(angle = 2 * WAIST_RANGE + 16)
            translate([CABLE_R[0], -1]) square([CABLE_R[1] - CABLE_R[0], LID_T + 2]);
        translate([0, 70, -1]) cylinder(d = 16.2, h = LID_T + 2);    // mode button (16 mm panel button)
    }
}

// Pegboard tray: boards mount with M3 nylon standoffs or zip ties.
module tray() {
    difference() {
        translate([-37, -28, 0]) rslab([74, 102, 3], 4);
        for (p = TRAY_BOSS) translate([p[0], p[1], -1]) cylinder(d = M3, h = 5);
        translate([-9.5, -12.5, -1]) rslab([19, 36, 5], 2);    // waist servo tower passes through
        for (x = [-32 : 8 : 32], y = [-20 : 8 : 68])
            if (min([for (p = TRAY_BOSS) norm([x - p[0], y - p[1]])]) > 7)
                translate([x, y, -1]) cylinder(d = 3.2, h = 5, $fn = 16);
    }
}

// ======================================================================
// WAIST: the torso turns on the bearing. Waist servo stands in the lower
// body, its clutch hub drives the waist plate tube from below.
// World frame (lower body frame).
// ======================================================================
WS_FACE_Z = LB[2];                         // clutch contact face = lid underside
WS_TAB_Z = WS_FACE_Z - LIMB_FACE;          // waist servo tab plane
module waist_frame() { translate([0, 0, WS_TAB_Z]) rotate([0, 0, 90]) children(); }

WP_DROP = CAP_T + WAIST_GAP;               // plate bottom -> inner race top
WP_FACE = -(WP_DROP + BR[2] + LID_T);      // contact face, plate frame
CLAMP_A = [90, 210, 330];
CLAMP_R = 17;

// Waist plate: torso bolts on top, tube goes down through the bearing.
// Local frame: plate bottom at z = 0, centred.
module waist() {
    difference() {
        union() {
            translate([-WP[0] / 2, -WP[1] / 2, 0]) rslab(WP, TO_R);
            translate([0, 0, -WP_DROP]) cylinder(d = BR_IN_OD - 0.5, h = WP_DROP + 0.01);       // rests on the inner race
            translate([0, 0, -WP_DROP - BR[2]]) cylinder(d = BR[0] - 0.1, h = BR[2] + 0.01, $fn = 96);
            translate([0, 0, WP_FACE]) cylinder(d = 30, h = LID_T + 0.01);
        }
        translate([0, 0, WP_FACE]) limb_socket_cut(WP[2] - WP_FACE, 4);
        for (a = CLAMP_A) rotate(a) translate([CLAMP_R, 0, -WP_DROP - BR[2]]) insert_hole(INS_L + 1);
        for (p = TORSO_BOSS) translate([p[0], p[1], -1]) cylinder(d = M3, h = WP[2] + 2);
        // cables down to the lower body
        hull() for (x = [-9, 9]) translate([x, 33.25, -1]) cylinder(d = 6.5, h = WP[2] + 2);
    }
}
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

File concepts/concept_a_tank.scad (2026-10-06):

// Concept A: "Tank" - tracked chassis, two 2-DOF arms, head on a pan servo,
// face = two 8x8 matrix eyes + 8x8 matrix mouth, HC-SR04 in the chest.
include <parts.scad>

module arm(s) {
    translate([s * 52, 0, 112]) {
        rotate([0, s * 90, 0]) mag_joint();
        translate([s * 13, 0, 0]) rotate([-45, 0, 0]) {
            limb(55);
            translate([0, 0, -55]) rotate([0, 90, 0]) color(C_GREY) cylinder(d = 18, h = 24, center = true);
            translate([0, 0, -55]) rotate([-50, 0, 0]) {
                limb(42, 20, 14);
                translate([0, 0, -44]) claw(8);
            }
        }
    }
}

module tank() {
    // tracks (robot drives along Y, faces -Y)
    for (s = [-1, 1]) translate([s * 72, 0, 31]) rotate([0, 0, 90]) track(175, 58, 32);
    // lower hull
    color(C_SHELL) translate([-56, -78, 14]) rbox([112, 156, 50], r = 8);
    // rubber bumper bars front/back
    for (y = [-1, 1]) color(C_DARK) translate([0, y * 88, 34]) rotate([0, 90, 0]) cylinder(d = 18, h = 176, center = true);
    // track fenders
    for (s = [-1, 1]) color(C_SHELL2) translate([s * 72 - 19, -90, 60]) rbox([38, 180, 8], r = 3);
    // torso
    color(C_SHELL) translate([-48, -40, 62]) rbox([96, 80, 62], r = 10);
    // chest ultrasonic behind a guard
    translate([0, -40, 92]) rotate([90, 0, 0]) hcsr04();
    color(C_SHELL2) translate([0, -42, 92]) rotate([90, 0, 0]) difference() {
        rbox([56, 30, 6], r = 3, center = true);
        for (x = [-13, 13]) translate([x, 0, 0]) cylinder(d = 17, h = 10, center = true);
    }
    // neck (pan servo housing)
    color(C_GREY) translate([0, 0, 124]) cylinder(d = 40, h = 10);
    // head
    translate([0, 0, 134]) {
        color(C_SHELL) translate([-50, -36, 0]) rbox([100, 72, 104], r = 12);
        // face plate
        color(C_DARK) translate([-44, -38, 6]) rbox([88, 8, 92], r = 3);
        for (x = [-21, 21]) translate([x, -38.5, 70]) rotate([90, 0, 0]) { matrix8x8(EYE); window(); }
        translate([0, -38.5, 26]) rotate([90, 0, 0]) { matrix8x8(SMILE); window(); }
        // antenna (flexible TPU)
        color(C_DARK) translate([30, 10, 102]) cylinder(d = 5, h = 25);
        color(C_LED) translate([30, 10, 129]) sphere(d = 10);
    }
    arm(-1); arm(1);
}

tank();

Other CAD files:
hardware/stl/chest_guard.stl
hardware/stl/track_link.stl
hardware/stl/bearing_cap.stl
hardware/stl/face_carrier.stl
concepts/concept_b_brick.scad
concepts/concept_c_digger.scad
concepts/parts.scad
concepts/tank_v2.scad
concepts/tank_v3.scad
concepts/tank_v4.scad
hardware/assembly.scad
hardware/base.scad
hardware/lib.scad
hardware/stl/bumper.stl
hardware/stl/fender.stl
hardware/stl/lower_body.stl
hardware/stl/tray.stl
hardware/stl/wheel_spacer.stl

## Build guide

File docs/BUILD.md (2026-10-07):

# Building Tank

Tank is a tough, kid-proof Arduino robot: a printed tracked base (a scaled-up
SMARS-style design), a printed body
with a waist that turns the whole upper body on the tank base, two slim arms
with claws, a 16 x 16 LED face, a Wi-Fi camera in the chest with a laser distance sensor, and a phone control page. It reuses
the Otto DIY "fat version" electronics (Nano + shield, servos, LED matrix,
buzzer).

Tank

## 1. Parts

### Already in your Otto kits

| Part | Qty | Notes |
|---|---|---|
| Otto Nano board (Nano + I/O shield) | 1 | body controller |
| Micro servos | 3 | 2 shoulders, 1 waist. Use **MG90S** (metal gears, same size) for the waist if you can, and for the shoulders too |
| MAX7219 8x8 LED matrix, 32 x 32 mm module | 4 | the face; buy one more if you have 3 |
| Passive buzzer, 12 mm | 1 | |
| Dupont cables | ~20 | |

### To buy

| Part | Qty | Notes |
|---|---|---|
| JGA25-370 gear motor, 6 V, 130-200 rpm, 4 mm D shaft | 2 | track drive; check the face screw spacing (`MOT_HOLE_SP`) and shaft offset (`MOT_OFF`) in `config.scad` |
| 608 skateboard bearings (8 x 22 x 7) | 12 | idlers and road wheels |
| M8 x 45 bolts + washers + nyloc nuts | 6 | wheel axles |
| M3 x 25 screws + M3 nyloc nuts | 42 | track link pins |
| M3 x 20 screws | 6 | sprocket halves to hub |
| M3 x 6 set screws | 2 | sprocket hub onto the motor shaft |
| *(or instead of all of the above)* TP101 / T101 aluminium tank chassis with motors | 1 | set `BASE = "bought"` in `config.scad` |
| ESP32-CAM (AI-Thinker, OV2640) + ESP32-CAM-MB USB adapter | 1 | camera, Wi-Fi |
| VL53L0X distance sensor breakout (GY-VL53L0XV2, ~25 x 10.7 mm) | 1 | |
| TB6612FNG motor driver | 1 | |
| 2 x 18650 holder (series, 7.4 V) + 2S protection board + 2 cells | 1 | |
| USB-C 2S (8.4 V) charging module | 1 | charge without opening the robot |
| 5 V 5 A buck converter (XL4015 type) | 1 | servos + logic + camera |
| KCD1 rocker switch (13 x 19 mm cut-out) | 1 | power |
| Mini slide switch SS12D00 | 1 | PROG / RUN |
| 16 mm momentary panel button | 1 | mode button |
| Resistors: 10k x 2 (battery sense), 1k + 2k (3.3 V divider) | | |
| 470 uF 10 V capacitor | 1 | across the ESP32-CAM 5 V input |
| 6808-2RS ball bearing (40 x 52 x 7 mm) | 1 | the waist turntable |
| Compression springs ~8 mm OD x 12 mm, 0.6-0.8 mm wire | 3 | clutches |
| M3 heat-set inserts (M3 x 5.7) | ~45 | |
| M3 socket screws 8, 10, 12, 20, 30 mm + washers + 3 nuts; M3 x 8 countersunk x 6 | | |
| M2 x 6 self-tapping screws | ~25 | servo tabs, horn-to-hub |
| Clear PETG / polycarbonate sheet, 2 mm | 72 x 72 + 24 x 24 | face window, lens window |
| Velcro strap 20 mm | 1 | holds the battery |

## 2. Printing

Export all parts with `hardware/export.sh` (or open `hardware/robot.scad`
in OpenSCAD and set `part`). Ready-made STLs are in `hardware/stl/`.

**Body parts in PETG** (PLA cracks when dropped): 4 walls, 5 top/bottom layers,
30 % gyroid, 0.2 mm layers. **TPU 95A** for bumpers and the antenna.

| STL | Qty | Material | Notes |
|---|---|---|---|
| lower_body | 1 | PETG | open side up, no supports |
| lid | 1 | PETG | |
| tray | 1 | PETG | pegboard for the boards |
| waist | 1 | PETG | already upside down (plate on the bed) |
| bearing_cap | 1 | PETG | |
| clamp_ring | 1 | PETG | |
| torso | 1 | PETG | already upside down (top on the bed); supports only in the two shoulder holes |
| chest_guard | 1 | PETG | |
| head_front | 1 | PETG | face down |
| head_back | 1 | PETG | |
| face_carrier | 1 | PETG | |
| base_frame | 1 | PETG | already upside down (deck on the bed), 102 x 176 mm |
| track_link | 42 | PETG | outside face down; 21 per track |
| sprocket_half | 4 | PETG | |
| sprocket_hub | 2 | PETG | flange down |
| wheel_half | 4 | PETG | idlers |
| road_wheel_half | 8 | PETG | |
| wheel_spacer | 6 | PETG | |
| arm | 2 | PETG | **mirror one** in the slicer for the left arm; supports under the claw |
| clutch_hub | 3 | PETG | ridges up |
| fender | 2 | PETG | **mirror one** |
| bumper | 2 | TPU | |
| antenna | 1 | TPU | |

## 3. Wiring

```
                 +-------------------- 7.4 V (2 x 18650) ---------------------+
 USB-C 2S charger -> battery -> rocker switch -+-> TB6612 VM (motors)        |
                                               +-> buck in  -> 5 V rail ------+
 5 V rail -> Nano 5V, servo V+ (shield), MAX7219 VCC, VL53L0X VIN, TB6612 VCC + STBY,
             ESP32-CAM 5V (470 uF cap at its pins). All grounds together.
 Battery + -> 10k -> A6 -> 10k -> GND   (battery voltage)
```

| Nano pin | Goes to |
|---|---|
| D0 (RX) | ESP32-CAM GPIO14 (TX), **through the PROG/RUN switch** |
| D1 (TX) | 1k -> ESP32-CAM GPIO15 (RX) -> 2k -> GND |
| D2 | mode button (other leg to GND) |
| D3 | buzzer + (other leg to GND) |
| D4 / D7 / D5 | TB6612 AIN1 / AIN2 / PWMA (left track) |
| D8 / A0 / D6 | TB6612 BIN1 / BIN2 / PWMB (right track) |
| D9 | left shoulder servo |
| A1 | right shoulder servo |
| A3 | waist servo |
| D10, A2 | free |
| D11 / D12 / D13 | MAX7219 DIN / CS / CLK (first module of the chain) |
| A4 / A5 | VL53L0X SDA / SCL |
| A6 | battery divider |

The four MAX7219 modules chain DOUT -> DIN. The camera and its board live in
the chest; the face cable goes down through the hole in the head floor into
the torso. Everything from the torso goes down to the Nano through the slot at
the back of the waist plate and the curved slot in the lid. Leave about 10 cm
of slack below the lid so the waist can turn both ways.

## 4. Assembly

0. **Base.** Inserts into the 6 deck holes. Bolt each motor to the inside of
   its side frame (2 x M3 from outside), shaft through the big hole, and zip-tie
   the can into its cradle. Screw the two sprocket halves onto a hub (3 x M3 x
   20), push it onto the motor shaft and tighten the set screw on the flat.
   Press a 608 into each wheel half; each wheel is two halves with a spacer
   between them on an M8 x 45 bolt (head inside the frame, washer and nyloc
   outside). Build each track from 21 links (M3 x 25 + nyloc per joint, horns
   facing in), wrap it round, join the last link, then slide the idler back in
   its slot until the track is snug and tighten the idler nut.
1. **Inserts.** Press M3 heat-set inserts into every round boss: lower body
   (6 on the rim, 4 bumper, 6 fender, 4 tray), lid (3 round the bearing
   housing), waist plate (3 in the bottom of the tube), torso (4 underneath,
   4 for the chest guard, 4 on top for the head), head (4 face-carrier,
   4 back-cap).
2. **Clutch hubs.** Screw each servo's round horn into a hub (2 x M2 from the
   horn side). Slide an M3 nut into the side slot later, after the hub is on the servo.
3. **Torso.** Fit the shoulder servos from inside so their tabs sit against the
   bulkheads, shafts out through the side holes; screw the tabs (M2). Centre
   every servo (90 deg) before fitting hubs. Press hubs onto the splines, drive the servo's centre screw through the
   hub, then slide in the nuts.
4. **Chest.** Slide the ESP32-CAM into its rails from below, lens forward;
   slide the VL53L0X into its rails. Put the 24 x 24 clear sheet into the chest
   guard and screw the guard on (4 x M3 x 8).
5. **Waist.** Press the 6808 bearing into the housing on the lid and screw the
   bearing cap on (3 x M3 x 8 countersunk). Feed the torso cables down through
   the slot at the back of the waist plate and bolt the torso onto the plate
   (4 x M3 x 10 from under the plate). Push the plate's tube down through the
   bearing, lay the torso on its back and screw the clamp ring onto the bottom
   of the tube (3 x M3 x 8 countersunk): now the body turns but can't lift out.
6. **Lower body.** Tray on its standoffs (the waist servo tower comes up
   through it), boards on the tray (nylon standoffs or zip ties), battery in its
   cradle with the strap, switches and charge port in the back, buzzer in its
   holder behind the grille, mode button in the lid. Drop the waist servo into
   its tower (tabs on the rim, 2 x M2), centre it, fit its clutch hub and slide
   the nut in.
7. **Close up.** Feed the torso cables through the curved slot in the lid to the
   Nano, leaving slack. Lid onto the lower body so the tube's grooves sit on the
   waist hub (6 x M3 countersunk). Drop the waist spring screw (M3 x 20 + washer
   + spring) through the hole in the top of the torso and tighten it into the
   hub nut until the body only turns by hand with a firm twist. Lower body onto
   the base deck (6 x M3 x 10 through the floor slots into the deck inserts), fenders and bumpers on.
8. **Arms.** Hang each arm on its shoulder hub: M3 x 30 + washer + spring from
   the outside into the hub nut. Tighten until the arm clicks round only with a
   firm twist.
9. **Head.** Clear 72 x 72 sheet against the inside of the face opening, the
   four matrices face-first into the carrier, carrier screwed on (4 x M3 x 10).
   Feed the face cable down through the floor hole, set the head on the torso
   and screw it down from inside (4 x M3 x 12 through the floor bosses). Push
   the TPU antenna into the top. Close the back cap.

## 5. Software

**Nano** (`firmware/robot_body`): Arduino IDE, board *Arduino Nano*, processor
*ATmega328P (Old Bootloader)* for most clones. Install the **VL53L0X** library by
Pololu. Flip PROG/RUN to **PROG**, upload, flip back to **RUN**.

**ESP32-CAM** (`firmware/robot_cam`): install the *esp32* boards package, board
*AI Thinker ESP32-CAM*. First upload on the ESP32-CAM-MB adapter; later uploads
work over Wi-Fi (port "tank", password = `AP_PASSWORD`).

**Faces:** edit the pictures in `tools/faces.txt`, then run
`python3 tools/make_faces.py` and upload the Nano again.

**Your own program:** edit `firmware/robot_body/my_program.h`; the commands are
listed at the top of `robot.h`. Press the mode button until the face shows 4.

## 6. First start and calibration

1. Power on: Tank says hello and shows mode 1 (Play).
2. Press the mode button until the face shows **5** (face test). Each module
   should show an arrow pointing up and 1-4 dots. Fix `MATRIX_TILE_X/Y`,
   `MATRIX_ROT` and `MATRIX_MIRROR` in `config.h` until it does.
3. Check the rest pose: shoulders ~40 deg forward, the body facing straight
   ahead. Adjust `trim` in `config.h`, or loosen the spring screw and click the
   part round one notch (60 deg) if it is far off. If the body turns right when
   you slide "Turn body" left on the phone, set `reversed` for the waist.
4. Drive from the phone: join Wi-Fi **Tank-XXXX** (password `tankrobot`), open
   **http://192.168.4.1**. If a track runs backwards set
   `LEFT_TRACK_REVERSED` / `RIGHT_TRACK_REVERSED`.

## 7. Using it

| Mode | Face shows | What Tank does |
|---|---|---|
| Play | 1 | turns its body to look around, blinks, waves at a hand held near its chest |
| Explore | 2 | drives on its own, backs off and turns away from obstacles |
| Dance | 3 | dances to a tune |
| My code | 4 | runs `myProgram()` once |
| Face test | 5 | wiring check for the face |
| Sleep | hold 1.5 s | sleepy face, nothing moves; hold again to wake |

The phone page has a joystick, Slow/Fast, a Light (the camera board's LED),
Bumper (the stop-before-a-wall guard, on by default), faces, sounds, arm poses,
modes and a Turn body slider. When the phone stops sending, the tracks stop within
0.4 s.

## Safety

* Lithium cells: use a protected 2S pack, charge only through the charger
  module, and keep the lid screwed shut.
* The shoulder and waist clutches click round instead of breaking when a child
  forces an arm or twists the body; the springs are inside, so no small parts
  come loose.
* With the body turned, the arms swing over the lower body, so the firmware
  keeps the shoulders at least `ARMS_CLEAR_ANGLE` (50 deg) up.
* `TRACK_MAX_PWM` and the Slow default keep it at walking pace.

## Things to check on your parts

* **Motors**: JGA25-370 sellers differ in face screw spacing and shaft offset;
  set `MOT_*` in `config.scad`. The TB6612 is fine for these at the default
  `TRACK_MAX_PWM`; if a motor stalls a lot, lower the speed.
* **Bought chassis instead**: set `BASE = "bought"` and `CH_*` to its size, and
  drill the deck to match the lower body floor slots.
* **Matrix modules**: the face carrier is for 32 x 32 mm (FC-16 style) modules.
  The older 50 x 32 mm boards with the chip below the LEDs won't fit; tell us
  and the carrier can be redrawn with the top row flipped.
* **Bearing**: the lid and plate are drawn for a 6808-2RS (40 x 52 x 7 mm);
  set `BR` in `config.scad` for another size.
* **ESP32-CAM lens position**: `CAM_X`, `CAM_Z` in `config.scad`.
* **Back panel heights**: the charge port (z 35 mm), PROG/RUN switch (z 26) and
  Nano USB opening (z 25-37) sit above the rear bumper. Mount the charger
  module and the Nano (on standoffs) so their sockets line up with the holes.

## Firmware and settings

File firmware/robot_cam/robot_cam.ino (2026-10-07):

// Tank robot: camera and phone control (AI-Thinker ESP32-CAM).
//
// What it does:
//   - makes a Wi-Fi network "Tank-XXXX" (or joins your home Wi-Fi, see config.h)
//   - serves a control page at http://192.168.4.1 with live video, a joystick,
//     and buttons for faces, sounds, arm poses and modes
//   - passes every command to the Nano over a serial link, and shows the
//     distance and battery readings the Nano sends back
//   - accepts over-the-air updates from the Arduino IDE (port "tank")
//
// Board: "AI Thinker ESP32-CAM" (esp32 core 2.x or 3.x). Flash it the first time
// on the ESP32-CAM-MB USB adapter; after that you can update it over Wi-Fi.

#include "esp_camera.h"
#include <WiFi.h>
#include <ArduinoOTA.h>
#include "esp_http_server.h"
#include "config.h"
#include "page.h"

// AI-Thinker ESP32-CAM camera pins
#define PWDN_GPIO_NUM 32
#define RESET_GPIO_NUM -1
#define XCLK_GPIO_NUM 0
#define SIOD_GPIO_NUM 26
#define SIOC_GPIO_NUM 27
#define Y9_GPIO_NUM 35
#define Y8_GPIO_NUM 34
#define Y7_GPIO_NUM 39
#define Y6_GPIO_NUM 36
#define Y5_GPIO_NUM 21
#define Y4_GPIO_NUM 19
#define Y3_GPIO_NUM 18
#define Y2_GPIO_NUM 5
#define VSYNC_GPIO_NUM 25
#define HREF_GPIO_NUM 23
#define PCLK_GPIO_NUM 22

HardwareSerial Link(2);
httpd_handle_t webServer = nullptr, streamServer = nullptr;
bool cameraOk = false;

// latest telemetry from the Nano: "T <distance mm> <battery mV> <mode> <face>"
volatile uint16_t telDist = 9999, telMv = 0;
volatile uint8_t telMode = 0, telFace = 0;
volatile uint32_t telAt = 0;
SemaphoreHandle_t linkLock;

void linkSend(const char *line) {
  xSemaphoreTake(linkLock, portMAX_DELAY);
  Link.print(line);
  Link.print('\n');
  xSemaphoreGive(linkLock);
}

void readLink() {
  static char buf[48];
  static uint8_t n = 0;
  while (Link.available()) {
    char c = Link.read();
    if (c == '\n' || c == '\r') {
      buf[n] = 0;
      if (n > 2 && buf[0] == 'T') {
        unsigned d, mv, mode, face;
        if (sscanf(buf + 1, "%u %u %u %u", &d, &mv, &mode, &face) == 4) {
          telDist = d; telMv = mv; telMode = mode; telFace = face; telAt = millis();
        }
      }
      n = 0;
    } else if (n < sizeof(buf) - 1) {
      buf[n++] = c;
    } else {
      n = 0;
    }
  }
}

// ---------------- camera ----------------
bool startCamera() {
  camera_config_t c = {};
  c.ledc_channel = LEDC_CHANNEL_0;
  c.ledc_timer = LEDC_TIMER_0;
  c.pin_d0 = Y2_GPIO_NUM; c.pin_d1 = Y3_GPIO_NUM; c.pin_d2 = Y4_GPIO_NUM; c.pin_d3 = Y5_GPIO_NUM;
  c.pin_d4 = Y6_GPIO_NUM; c.pin_d5 = Y7_GPIO_NUM; c.pin_d6 = Y8_GPIO_NUM; c.pin_d7 = Y9_GPIO_NUM;
  c.pin_xclk = XCLK_GPIO_NUM; c.pin_pclk = PCLK_GPIO_NUM; c.pin_vsync = VSYNC_GPIO_NUM;
  c.pin_href = HREF_GPIO_NUM; c.pin_sccb_sda = SIOD_GPIO_NUM; c.pin_sccb_scl = SIOC_GPIO_NUM;
  c.pin_pwdn = PWDN_GPIO_NUM; c.pin_reset = RESET_GPIO_NUM;
  c.xclk_freq_hz = 20000000;
  c.pixel_format = PIXFORMAT_JPEG;
  c.frame_size = CAMERA_FRAME_SIZE;
  c.jpeg_quality = CAMERA_JPEG_QUALITY;
  c.fb_count = psramFound() ? 2 : 1;
  c.fb_location = psramFound() ? CAMERA_FB_IN_PSRAM : CAMERA_FB_IN_DRAM;
  c.grab_mode = CAMERA_GRAB_LATEST;
  if (esp_camera_init(&c) != ESP_OK) return false;
  sensor_t *s = esp_camera_sensor_get();
  s->set_vflip(s, CAMERA_FLIP);
  s->set_hmirror(s, CAMERA_FLIP);
  return true;
}

// ---------------- web handlers ----------------
esp_err_t indexHandler(httpd_req_t *req) {
  httpd_resp_set_type(req, "text/html");
  return httpd_resp_send(req, PAGE_HTML, HTTPD_RESP_USE_STRLEN);
}

// /cmd?c=D%2050%2050  -> one line to the Nano. Only known command letters pass.
esp_err_t cmdHandler(httpd_req_t *req) {
  char query[64], value[40];
  if (httpd_req_get_url_query_str(req, query, sizeof query) != ESP_OK ||
      httpd_query_key_value(query, "c", value, sizeof value) != ESP_OK) {
    httpd_resp_send_err(req, HTTPD_400_BAD_REQUEST, "missing c");
    return ESP_FAIL;
  }
  // decode %20 and + into spaces
  char line[40]; uint8_t n = 0;
  for (char *p = value; *p && n < sizeof(line) - 1; p++) {
    if (*p == '+') line[n++] = ' ';
    else if (*p == '%' && p[1] && p[2]) { char h[3] = {p[1], p[2], 0}; line[n++] = (char)strtol(h, nullptr, 16); p += 2; }
    else line[n++] = *p;
  }
  line[n] = 0;
  if (!strchr("DJFSPMGH", line[0]) || strchr(line, '\n')) {
    httpd_resp_send_err(req, HTTPD_400_BAD_REQUEST, "unknown command");
    return ESP_FAIL;
  }
  linkSend(line);
  httpd_resp_set_hdr(req, "Cache-Control", "no-store");
  return httpd_resp_send(req, "ok", 2);
}

esp_err_t statusHandler(httpd_req_t *req) {
  char json[96];
  bool fresh = millis() - telAt < 2000;
  snprintf(json, sizeof json, "{\"dist\":%u,\"mv\":%u,\"mode\":%u,\"face\":%u,\"nano\":%s,\"camera\":%s}",
           telDist, telMv, telMode, telFace, fresh ? "true" : "false", cameraOk ? "true" : "false");
  httpd_resp_set_type(req, "application/json");
  httpd_resp_set_hdr(req, "Cache-Control", "no-store");
  return httpd_resp_send(req, json, HTTPD_RESP_USE_STRLEN);
}

esp_err_t lightHandler(httpd_req_t *req) {
  char query[16], v[4] = "0";
  if (httpd_req_get_url_query_str(req, query, sizeof query) == ESP_OK) httpd_query_key_value(query, "on", v, sizeof v);
  digitalWrite(FLASH_LED_PIN, v[0] == '1');
  return httpd_resp_send(req, "ok", 2);
}

#define BOUNDARY "tankframe"
esp_err_t streamHandler(httpd_req_t *req) {
  if (!cameraOk) { httpd_resp_send_err(req, HTTPD_500_INTERNAL_SERVER_ERROR, "no camera"); return ESP_FAIL; }
  httpd_resp_set_type(req, "multipart/x-mixed-replace;boundary=" BOUNDARY);
  httpd_resp_set_hdr(req, "Access-Control-Allow-Origin", "*");
  char head[80];
  while (true) {
    camera_fb_t *fb = esp_camera_fb_get();
    if (!fb) return ESP_FAIL;
    int len = snprintf(head, sizeof head, "\r\n--" BOUNDARY "\r\nContent-Type: image/jpeg\r\nContent-Length: %u\r\n\r\n", fb->len);
    esp_err_t r = httpd_resp_send_chunk(req, head, len);
    if (r == ESP_OK) r = httpd_resp_send_chunk(req, (const char *)fb->buf, fb->len);
    esp_camera_fb_return(fb);
    if (r != ESP_OK) return r;   // the phone went away
  }
}

void startServers() {
  httpd_config_t cfg = HTTPD_DEFAULT_CONFIG();
  cfg.server_port = 80;
  cfg.ctrl_port = 32768;
  httpd_uri_t uris[] = {
    {"/", HTTP_GET, indexHandler, nullptr},
    {"/cmd", HTTP_GET, cmdHandler, nullptr},
    {"/status", HTTP_GET, statusHandler, nullptr},
    {"/light", HTTP_GET, lightHandler, nullptr},
  };
  if (httpd_start(&webServer, &cfg) == ESP_OK)
    for (auto &u : uris) httpd_register_uri_handler(webServer, &u);

  httpd_config_t scfg = HTTPD_DEFAULT_CONFIG();
  scfg.server_port = 81;
  scfg.ctrl_port = 32769;
  httpd_uri_t stream = {"/stream", HTTP_GET, streamHandler, nullptr};
  if (httpd_start(&streamServer, &scfg) == ESP_OK) httpd_register_uri_handler(streamServer, &stream);
}

// ---------------- Wi-Fi ----------------
void startWifi() {
  WiFi.setHostname(HOSTNAME);
  if (strlen(HOME_SSID)) {
    WiFi.mode(WIFI_STA);
    WiFi.begin(HOME_SSID, HOME_PASSWORD);
    for (int i = 0; i < 40 && WiFi.status() != WL_CONNECTED; i++) delay(250);
    if (WiFi.status() == WL_CONNECTED) {
      Serial.printf("Joined %s, open http://%s\n", HOME_SSID, WiFi.localIP().toString().c_str());
      return;
    }
  }
  uint8_t mac[6];
  WiFi.mode(WIFI_AP);
  WiFi.softAPmacAddress(mac);
  char ssid[16];
  snprintf(ssid, sizeof ssid, "Tank-%02X%02X", mac[4], mac[5]);
  WiFi.softAP(ssid, AP_PASSWORD);
  Serial.printf("Network %s, open http://%s\n", ssid, WiFi.softAPIP().toString().c_str());
}

void setup() {
  Serial.begin(115200);
  pinMode(FLASH_LED_PIN, OUTPUT);
  digitalWrite(FLASH_LED_PIN, LOW);
  linkLock = xSemaphoreCreateMutex();
  Link.begin(LINK_BAUD, SERIAL_8N1, LINK_RX_PIN, LINK_TX_PIN);
  cameraOk = startCamera();
  if (!cameraOk) Serial.println("Camera did not start: check the ribbon cable");
  startWifi();
  startServers();
  ArduinoOTA.setHostname(HOSTNAME);
  ArduinoOTA.setPassword(AP_PASSWORD);
  ArduinoOTA.begin();
  linkSend("S 1");   // Tank says hello when the phone link is up
}

void loop() {
  readLink();
  ArduinoOTA.handle();
  delay(2);
}

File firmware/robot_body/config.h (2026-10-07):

// Tank robot body controller (Arduino Nano on the Otto Nano shield).
// Everything you might need to tune for your own build is in this file.
#pragma once
#include <Arduino.h>

// ---------------- pins ----------------
// D0/D1 are the link to the ESP32-CAM. Flip the PROG/RUN switch to PROG
// before uploading to the Nano over USB.
const uint8_t PIN_MODE_BUTTON = 2;   // panel button to GND
const uint8_t PIN_BUZZER      = 3;   // passive buzzer
const uint8_t PIN_AIN1 = 4, PIN_PWMA = 5, PIN_AIN2 = 7;    // TB6612 channel A = left track
const uint8_t PIN_BIN1 = 8, PIN_PWMB = 6, PIN_BIN2 = A0;   // TB6612 channel B = right track
const uint8_t PIN_MATRIX_DIN = 11, PIN_MATRIX_CS = 12, PIN_MATRIX_CLK = 13;  // hardware SPI
const uint8_t PIN_BATTERY = A6;      // 10k / 10k divider from the battery +
// Servo pins are in the JOINTS table below. A4/A5 = I2C to the VL53L0X.

// ---------------- tracks ----------------
const bool LEFT_TRACK_REVERSED  = false;   // flip if a track runs backwards
const bool RIGHT_TRACK_REVERSED = false;
const uint8_t TRACK_MAX_PWM = 200;         // 255 = full speed; lower = gentler toy
const uint8_t TRACK_ACCEL   = 4;           // PWM steps per 5 ms (soft starts save gears)
const uint16_t REMOTE_TIMEOUT_MS = 400;    // stop if the phone goes quiet

// ---------------- servos ----------------
// Angles: shoulder 0 = arm straight down, 90 = pointing forward, 180 = straight up.
// Waist 90 = facing ahead, bigger = turned left. The elbows are a fixed bend.
// D10 and A2 are free (they drove the elbows in an earlier design).
// trim: degrees added so the joint matches the drawing at rest (calibrate once).
struct JointConfig {
  uint8_t pin;
  bool reversed;
  int8_t trim;
  uint8_t minAngle, maxAngle, restAngle;
};
enum Joint : uint8_t { L_SHOULDER, R_SHOULDER, WAIST, JOINT_COUNT };
const JointConfig JOINTS[JOINT_COUNT] = {
  //  pin  reversed trim  min  max  rest
  {   9,   true,     0,   40, 180,  40 },   // left shoulder (below 40 the claw hits the fender)
  {  A1,   false,    0,   40, 180,  40 },   // right shoulder
  {  A3,   false,    0,   25, 155,  90 },   // waist (65 each way: the cables allow about 70)
};
const uint8_t ARMS_CLEAR_ANGLE = 50;       // with the waist turned, the arms swing over the
                                           // lower body: keep the shoulders at least this high
const uint16_t SERVO_SPEED_DEG_S = 180;    // how fast joints move
const uint16_t SERVO_DETACH_MS   = 1500;   // stop holding after this long still: saves power,
                                           // and lets little hands move the arms freely

// ---------------- face: 4 x MAX7219 in a 2x2 square ----------------
// Module 0 is the first one wired to the Nano. For each module give its tile
// (column, row) in the square and its rotation in quarter turns clockwise.
// Run mode 4 (face test) to check: each module shows its number and an arrow
// pointing up. Fix these values until all four arrows point up.
const uint8_t MATRIX_TILE_X[4] = {0, 1, 0, 1};
const uint8_t MATRIX_TILE_Y[4] = {0, 0, 1, 1};
const uint8_t MATRIX_ROT[4]    = {0, 0, 0, 0};
const bool MATRIX_MIRROR = false;          // some modules wire columns right-to-left
const uint8_t MATRIX_BRIGHTNESS = 4;       // 0..15

// ---------------- distance sensor ----------------
const uint16_t STOP_DISTANCE_MM    = 120;  // never drive forward closer than this
const uint16_t EXPLORE_TURN_MM     = 250;  // explore mode turns away at this distance
const uint16_t HELLO_DISTANCE_MM   = 150;  // a hand this close says hello in play mode

// ---------------- battery (2 x 18650 in series) ----------------
const uint16_t BATTERY_LOW_MV  = 6800;     // sleepy face, half speed
const uint16_t BATTERY_EMPTY_MV = 6400;    // stop driving, ask for a charge
const float BATTERY_DIVIDER = 2.0;         // 10k / 10k

// ---------------- link to the ESP32-CAM ----------------
const uint32_t LINK_BAUD = 115200;
const uint16_t TELEMETRY_MS = 200;

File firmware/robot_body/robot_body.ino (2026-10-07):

// Tank robot: body controller for the Arduino Nano (Otto Nano shield).
//
// Modes (short press of the mode button cycles, the face shows the number):
//   1 PLAY     looks around, blinks, says hello when a hand comes close
//   2 EXPLORE  drives around on its own and turns away from obstacles
//   3 DANCE    dances to a tune
//   4 MY PROGRAM  runs myProgram() from my_program.h once
//   5 FACE TEST   shows which face module is which (for wiring)
// Hold the button 1.5 s to go to sleep (and again to wake up).
// The phone app (ESP32-CAM) can drive and control everything; when it stops
// sending, Tank goes back to the mode it was in.
//
// Upload: Tools > Board > Arduino Nano, Processor > ATmega328P (Old Bootloader
// for most clones). Flip the PROG/RUN switch to PROG first.
// Needs the "VL53L0X" library by Pololu (Library Manager).

#include "config.h"
#include "robot.h"
#include "face.h"
#include "sound.h"
#include "joints.h"
#include "tracks.h"
#include "sensors.h"
#include "my_program.h"

enum Mode : uint8_t { MODE_PLAY, MODE_EXPLORE, MODE_DANCE, MODE_PROGRAM, MODE_FACE_TEST, MODE_COUNT, MODE_SLEEP = 99 };
Mode mode = MODE_PLAY;
Mode modeBeforeSleep = MODE_PLAY;
bool remoteActive = false;
uint32_t lastRemoteDrive = 0, lastRemoteAny = 0, lastTelemetry = 0;
uint32_t nextIdleMove = 0, helloCooldown = 0;
bool lowBatteryShown = false;
bool pendingShort = false, pendingLong = false;   // button presses seen while busy

// ---------------- serial link to the ESP32-CAM ----------------
// Lines of text, for example "D 50 -50" (drive), "F 1" (face), "S 2" (sound),
// "J 2 120" (waist to 120 degrees), "P 1" (pose), "M 1" (mode), "G 0" (guard off).
char line[32];
uint8_t lineLen = 0;

void setMode(Mode m);

void doPose(uint8_t p) {
  switch (p) {
    case 0: robot.rest(); break;
    case 1: robot.armsUp(); break;
    case 2: robot.hug(); break;
    case 3: robot.arms(60, 60); break;                                // point forward
    case 4: robot.arms(170, 40); break;                               // one arm up
    case 5: robot.wave(); break;
  }
}

void handleLine(char *s) {
  char cmd = s[0];
  int a = 0, b = 0;
  char *p = s + 1;
  a = strtol(p, &p, 10);
  b = strtol(p, &p, 10);
  lastRemoteAny = millis();
  switch (cmd) {
    case 'D':
      remoteActive = true;
      lastRemoteDrive = millis();
      robot.drive(constrain(a, -100, 100), constrain(b, -100, 100));
      break;
    case 'J': if (a >= 0 && a < JOINT_COUNT) Joints::move((Joint)a, b); break;
    case 'F': robot.face((Expression)constrain(a, 0, EXPRESSION_COUNT - 1)); break;
    case 'S': robot.sound((Sound)constrain(a, 0, SOUND_COUNT - 1)); break;
    case 'P': doPose(a); break;
    case 'M': if (a >= 0 && a < MODE_COUNT) setMode((Mode)a); break;
    case 'G': robot.guard = a != 0; break;
    case 'H': break;   // heartbeat
  }
}

void readLink() {
  while (Serial.available()) {
    char c = Serial.read();
    if (c == '\n' || c == '\r') {
      if (lineLen) { line[lineLen] = 0; handleLine(line); lineLen = 0; }
    } else if (lineLen < sizeof(line) - 1) {
      line[lineLen++] = c;
    } else {
      lineLen = 0;   // garbage: drop it
    }
  }
  // the phone stopped sending drive commands: stop the tracks
  if (remoteActive && millis() - lastRemoteDrive > REMOTE_TIMEOUT_MS) {
    robot.stop();
    remoteActive = false;
  }
}

void sendTelemetry() {
  if (millis() - lastTelemetry < TELEMETRY_MS) return;
  lastTelemetry = millis();
  Serial.print(F("T "));
  Serial.print(Sensors::distanceMm());
  Serial.print(' ');
  Serial.print(Sensors::batteryMv());
  Serial.print(' ');
  Serial.print(mode == MODE_SLEEP ? 9 : (uint8_t)mode);
  Serial.print(' ');
  Serial.println((uint8_t)Face::current());
}

// ---------------- modes ----------------
void setMode(Mode m) {
  robot.stop();
  robot.rest();
  Face::testPatternOff();
  mode = m;
  if (m == MODE_SLEEP) {
    robot.face(SLEEPY);
    robot.sound(SND_SLEEP);
    return;
  }
  robot.face(NEUTRAL);
  Face::showDigit(m + 1);
  Sounds::beeps(m + 1);
  if (m == MODE_FACE_TEST) Face::testPattern();
}

void playMode() {
  uint32_t t = millis();
  // say hello to a hand in front of the chest
  if (robot.distance() < HELLO_DISTANCE_MM && t > helloCooldown) {
    helloCooldown = t + 8000;
    robot.face(HAPPY);
    robot.sound(SND_HELLO);
    robot.wave();
    robot.face(NEUTRAL);
    return;
  }
  // now and then, look around
  if (t > nextIdleMove) {
    nextIdleMove = t + random(3000, 8000);
    int8_t dir = random(-1, 2);
    robot.look(dir);   // turns the upper body at the waist
    if (random(4) == 0) robot.arms(random(40, 120), random(40, 120));
    else robot.arms(JOINTS[L_SHOULDER].restAngle, JOINTS[R_SHOULDER].restAngle);
  }
}

void exploreMode() {
  if (robot.distance() > EXPLORE_TURN_MM) {
    robot.drive(45, 45);
    return;
  }
  robot.stop();
  robot.face(SURPRISED);
  robot.sound(SND_UHOH);
  robot.backward(400, 45);
  int8_t dir = random(2) ? 1 : -1;
  robot.look(dir);
  // spin until the way ahead is clear (give up after 3 s)
  robot.drive(dir * 50, -dir * 50);
  uint32_t until = millis() + 3000;
  while (millis() < until && robot.distance() < EXPLORE_TURN_MM + 100) {
    if (!robot.wait(20)) return;
  }
  robot.stop();
  robot.look(0);
  robot.face(NEUTRAL);
}

void danceMode() {
  robot.face(HAPPY);
  robot.sound(SND_DANCE);
  for (uint8_t i = 0; i < 2 && !robot.cancelled; i++) {
    robot.arms(170, 40); robot.look(-1); robot.wait(450);
    robot.arms(40, 170); robot.look(1);  robot.wait(450);
  }
  robot.face(SILLY);
  robot.turnLeft(600, 60);
  robot.armsUp(); robot.wait(400);
  robot.face(WINK);
  robot.turnRight(600, 60);
  robot.hug(); robot.wait(500);
  robot.face(LOVE);
  robot.rest(); robot.look(0);
  robot.wait(1200);
}

void sleepMode() {
  robot.stop();
}

// Called from inside robot.wait(): lets the button and the phone interrupt long moves.
void checkInterrupts() {
  readLink();
  if (Sensors::buttonPressed()) { pendingShort = true; robot.cancelled = true; }
  if (Sensors::buttonLongPressed()) { pendingLong = true; robot.cancelled = true; }
  if (remoteActive && mode != MODE_PLAY) robot.cancelled = true;
}

// ---------------- setup / loop ----------------
void setup() {
  Serial.begin(LINK_BAUD);
  randomSeed(analogRead(A7));
  robot.begin();
  robot.hook = checkInterrupts;
  Serial.println(F("I tank"));
  robot.face(HAPPY);
  robot.sound(SND_HELLO);
  robot.wait(800);
  setMode(MODE_PLAY);
}
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

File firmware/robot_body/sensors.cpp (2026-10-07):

#include "sensors.h"
#include <Wire.h>
#include <VL53L0X.h>
#include "config.h"

namespace {
VL53L0X tof;
bool tofOk = false;
uint16_t dist = 9999;
uint32_t distAt = 0;
uint16_t battMv = 0;
uint32_t lastBatt = 0;
bool btnDown = false, shortFlag = false, longFlag = false, longFired = false;
uint32_t btnSince = 0, lastBtnChange = 0;
}  // namespace

namespace Sensors {
void begin() {
  pinMode(PIN_MODE_BUTTON, INPUT_PULLUP);
  Wire.begin();
  Wire.setWireTimeout(3000, true);     // a loose sensor cable must never freeze the robot
  tof.setTimeout(30);
  tofOk = tof.init();
  if (tofOk) {
    tof.setMeasurementTimingBudget(33000);
    tof.startContinuous(50);
  }
  battMv = analogRead(PIN_BATTERY) * (5000.0f * BATTERY_DIVIDER / 1023.0f);
}

void update() {
  uint32_t t = millis();
  if (tofOk && (tof.readReg(VL53L0X::RESULT_INTERRUPT_STATUS) & 0x07)) {
    uint16_t mm = tof.readReg16Bit(VL53L0X::RESULT_RANGE_STATUS + 10);
    tof.writeReg(VL53L0X::SYSTEM_INTERRUPT_CLEAR, 0x01);
    dist = (mm == 0 || mm > 2000) ? 9999 : mm;
    distAt = t;
  }
  if (t - distAt > 500) dist = 9999;   // stale reading: assume clear

  if (t - lastBatt > 500) {
    lastBatt = t;
    uint16_t mv = analogRead(PIN_BATTERY) * (5000.0f * BATTERY_DIVIDER / 1023.0f);
    battMv = (battMv * 3 + mv) / 4;    // smooth out motor dips
  }

  bool down = digitalRead(PIN_MODE_BUTTON) == LOW;
  if (down != btnDown && t - lastBtnChange > 30) {
    lastBtnChange = t;
    btnDown = down;
    if (down) { btnSince = t; longFired = false; }
    else if (!longFired) shortFlag = true;
  }
  if (btnDown && !longFired && t - btnSince > 1500) { longFired = true; longFlag = true; }
}

uint16_t distanceMm() { return dist; }
bool hasDistance() { return tofOk; }
uint16_t batteryMv() { return battMv; }
bool buttonPressed() { bool f = shortFlag; shortFlag = false; return f; }
bool buttonLongPressed() { bool f = longFlag; longFlag = false; return f; }
}  // namespace Sensors

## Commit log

2026-10-06 Add three robot toy concept models and renders
    Claude-Session: https://claude.ai/code/session_01D8vzBvTu69oMrGQGTpA3ip
    [concept_a_tank.scad, concept_b_brick.scad, concept_c_digger.scad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]
2026-10-06 Add Tank v2: bought track chassis and ESP32-CAM camera
    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
    [tank_v2.scad]
2026-10-06 Add Tank v3: camera and VL53L0X distance sensor in the chest
    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
    [tank_v3.scad]
2026-10-06 Add Tank v4: 16x16 face from four MAX7219 modules
    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
    [parts.scad, tank_v4.scad]
2026-10-07 Full Tank design: printable parts, firmware, phone app, build guide
    - hardware/: parametric OpenSCAD body, arms with spring clutches, head with
    16x16 face, bumpers and fenders; STLs, renders and export script
    - firmware/robot_body: Nano body controller (tracks, servos, face, sound,
    distance sensor, modes, simple robot API for kids' programs)
    - firmware/robot_cam: ESP32-CAM video stream and phone control page
    - tools/: face editor script; docs/BUILD.md: parts, wiring, assembly
    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
    [antenna.stl, assembly.scad, bumper.stl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]
2026-10-07 Fix the head to the torso, drop the neck servo
    The head now bolts onto the torso top (4 x M3 into heat-set inserts),
    so it turns with the body. Removed the neck servo, its bulkhead and
    clutch from the model; the firmware loses the NECK joint and the phone
    page its head slider. Play mode turns a little on the tracks to look
    around. Build guide, page text, STLs and renders updated.
    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
    [antenna.stl, assembly.scad, bumper.stl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]
2026-10-07 Turn the upper body at the waist; slim one-piece arms
    The torso, arms and head now turn together on a 6808 bearing in the lid,
    driven by a waist servo standing in the lower body through the same
    spring clutch as the shoulders. A clamp ring under the bearing lets the
    robot be lifted by its head. The arms go back to the slim v4 shape: one
    printed piece with a fixed elbow bend and a claw, moved by the shoulder
    only. Firmware swaps the two elbows for the waist (A3) and keeps the
    arms raised while the body is turned; the phone page gets a Turn body
    slider. Tray trimmed to clear the lid columns and rear bumper bosses.
    Claude-Ses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
    [antenna.stl, arm.stl, assembly.scad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]
2026-10-07 Printed tracked base (scaled-up SMARS style) replaces the bought chassis
    New hardware/base.scad: one-piece deck and side frames, two JGA25-370
    gear motors (right track driven at the front, left at the rear so the
    motors sit side by side), split sprockets on a set-screw hub, idlers and
    road wheels on 608 bearings, and 21 printed links per track joined with
    M3 x 25 screws. BASE = "bought" keeps the TP101 option. Lower body floor
    slots move to match the deck inserts; fenders sit 2 mm higher.
    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
    [antenna.stl, arm.stl, assembly.scad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]
